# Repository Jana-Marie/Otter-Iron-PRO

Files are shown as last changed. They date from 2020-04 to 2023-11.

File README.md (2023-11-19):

# Otter-Iron-PRO

USB-PD soldering station for JBC C245 handles based on the [Otter-Iron](https://github.com/Jana-Marie/Otter-Iron).

 - v1.0 tested, works but not great
 - v1.1 untested, wont be tested
 - v2.0 tested, kinda works, could be much more stable

## Firmware

 - Requests and configures for USB-PD profile of 30 W or 80 W (allows variable).
 - Current limit automatically set based on PD profile available.
 - Profiles can be changed in firmware and enumerated profile will show at start up.
 - Prevents MOSFET driving if no/incompatiable USB-PD profile is advertised; allows setup/flashing with standard USB port.

## v2.0

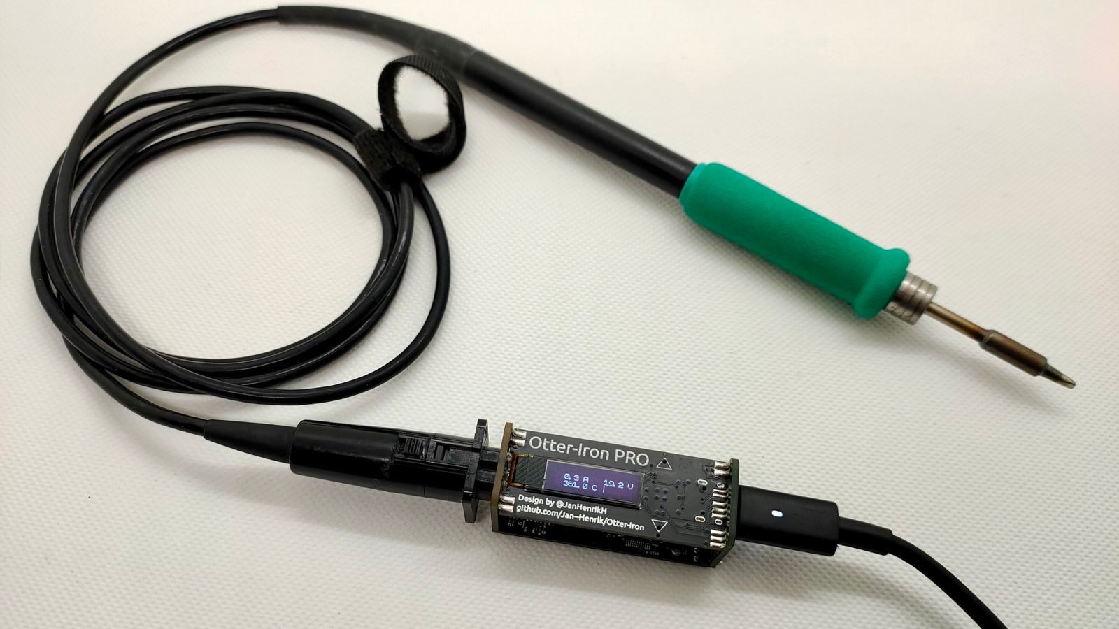
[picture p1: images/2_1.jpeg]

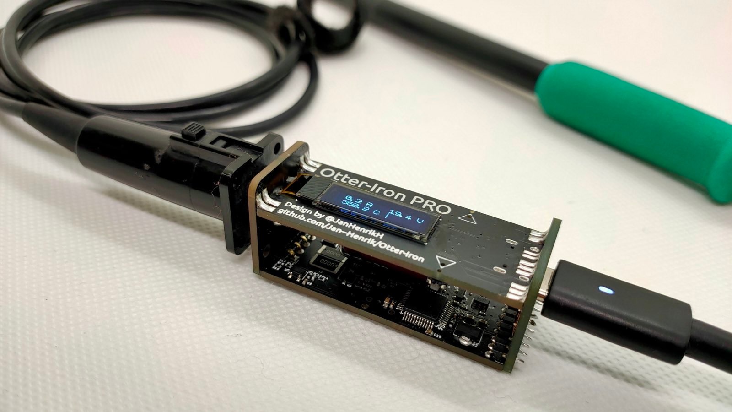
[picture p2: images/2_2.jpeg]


## v1.0

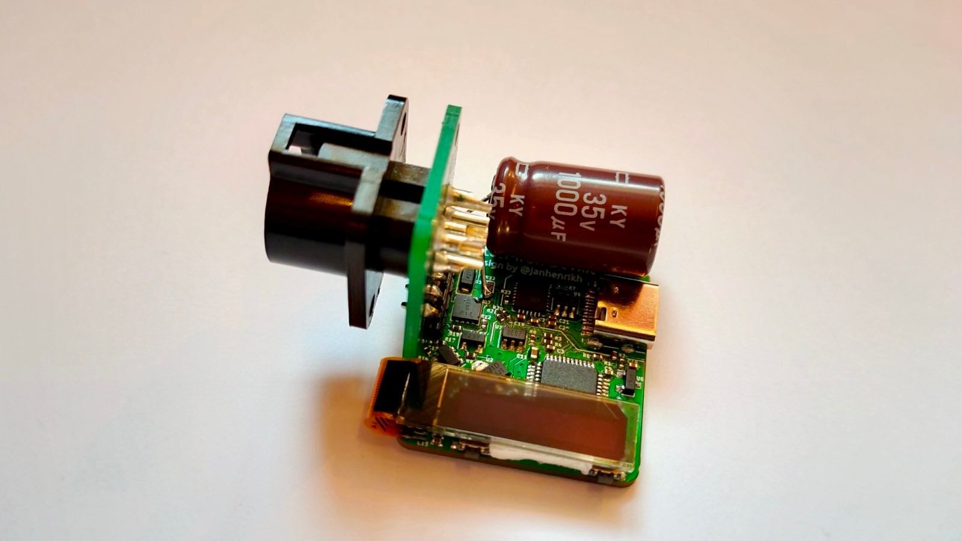
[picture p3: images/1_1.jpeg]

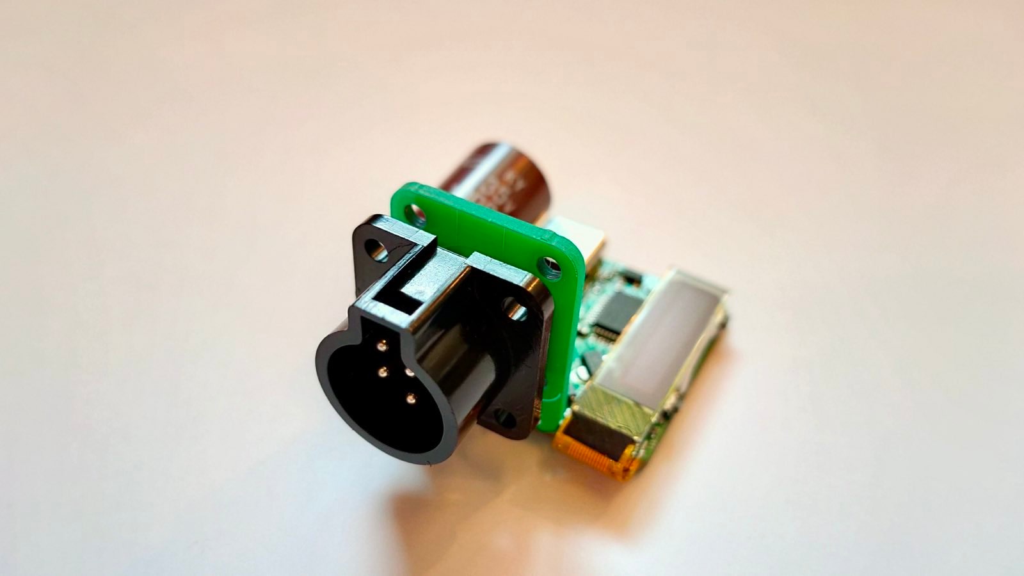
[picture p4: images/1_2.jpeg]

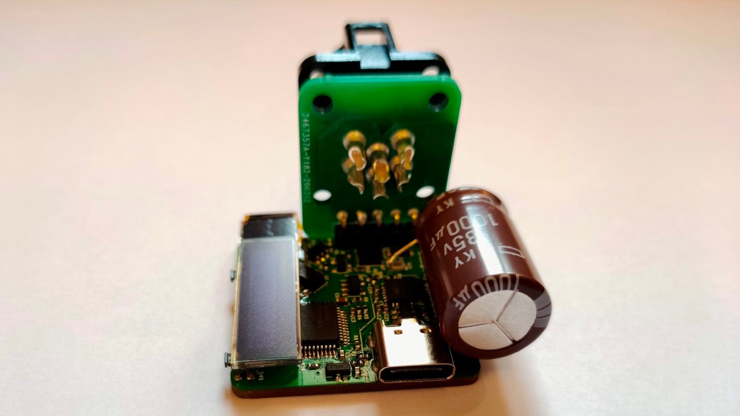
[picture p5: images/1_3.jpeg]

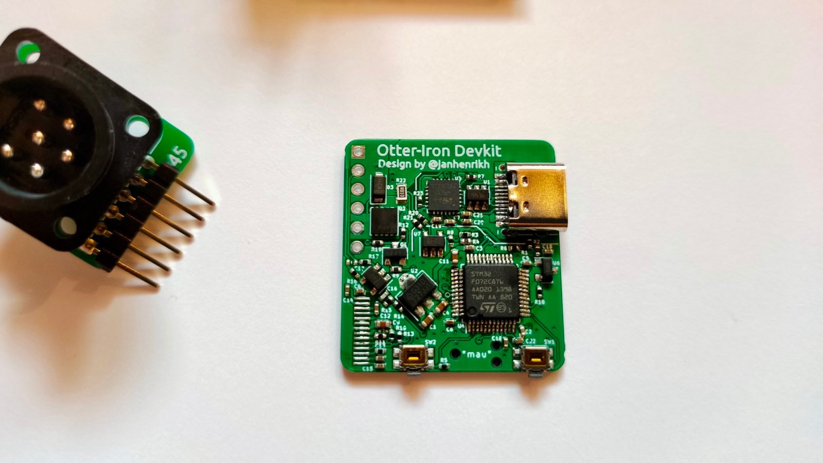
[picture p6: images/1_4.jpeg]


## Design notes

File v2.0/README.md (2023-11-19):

[BOM](https://github.com/jeanthom/Otter-Iron-PRO-BOM)




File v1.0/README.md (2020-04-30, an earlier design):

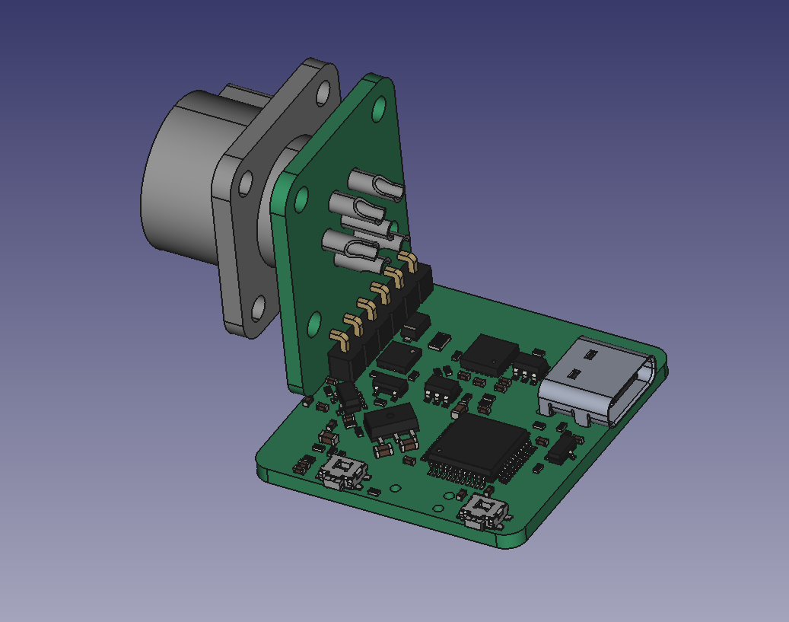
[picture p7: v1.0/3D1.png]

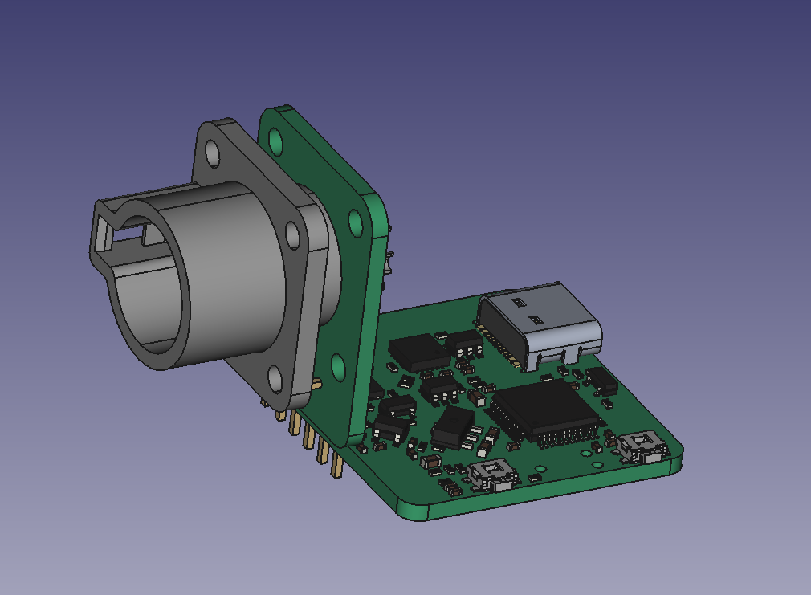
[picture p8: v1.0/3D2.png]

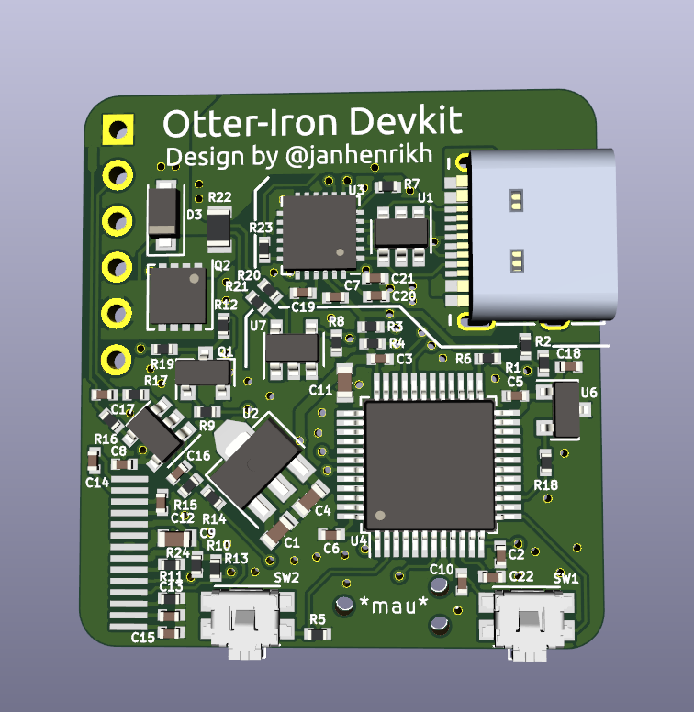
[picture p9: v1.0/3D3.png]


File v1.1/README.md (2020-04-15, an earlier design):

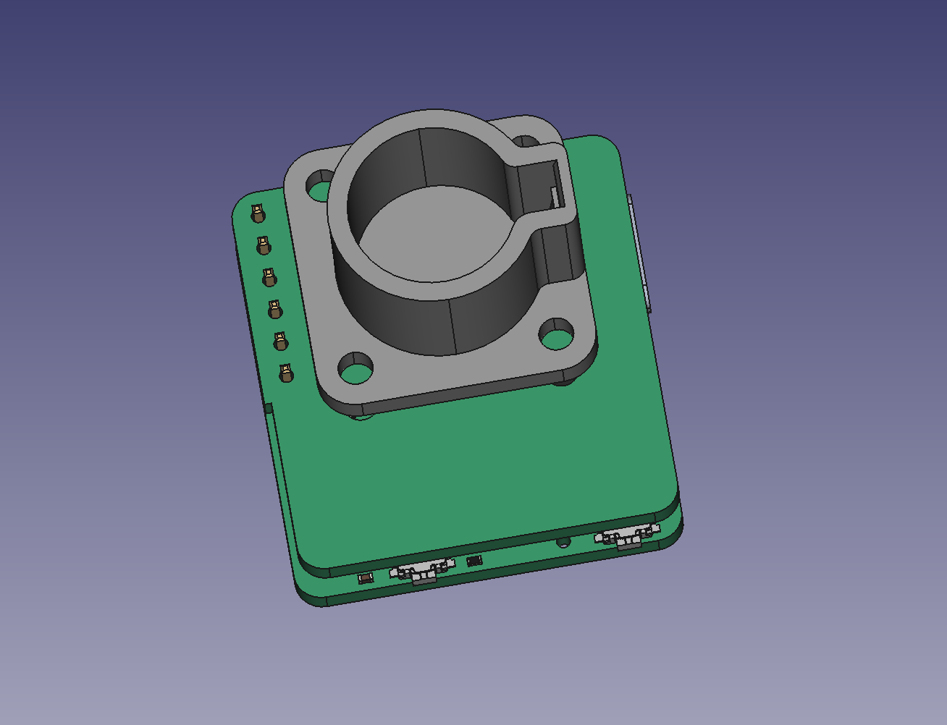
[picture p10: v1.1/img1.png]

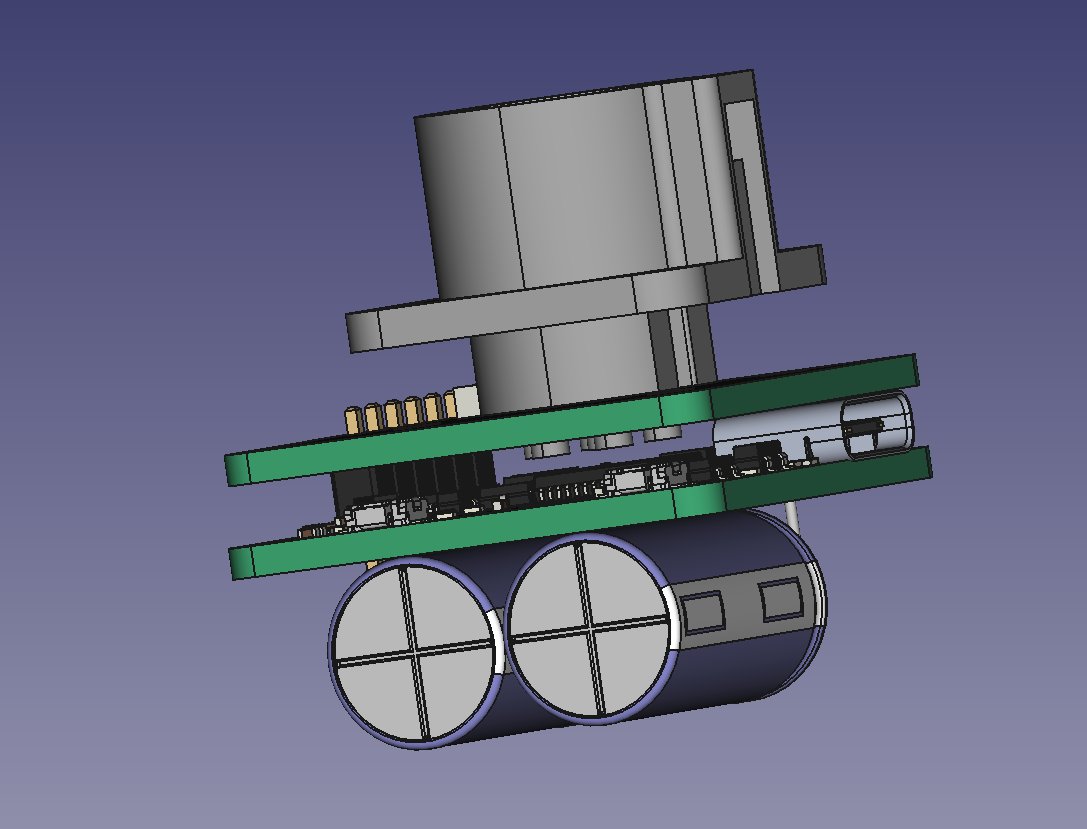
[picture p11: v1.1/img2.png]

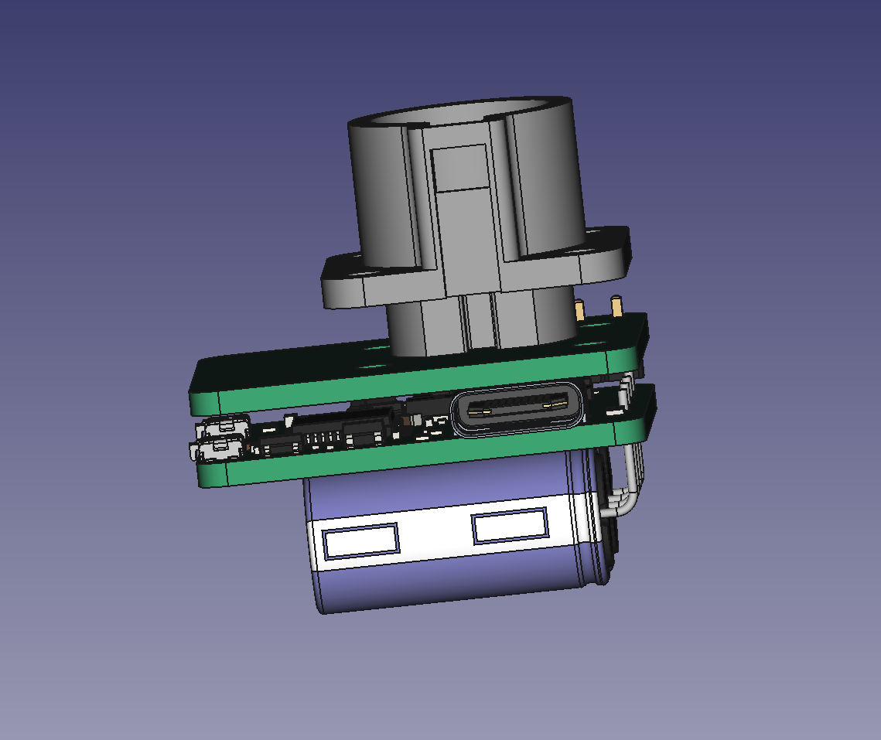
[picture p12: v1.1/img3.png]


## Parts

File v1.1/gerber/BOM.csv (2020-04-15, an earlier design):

Comment | Designator | Footprint | LCSC
1μF 25V | C1,C4,C11,C9 | otter:C_0603 | C15849
1μF 25V | C15,C13,C14,C12,C20,C19 | otter:C_0402 | C52923
18p | C16 | otter:C_0402 | C1549
DNP | C17 | otter:C_0402
0.1μF | C3,C5,C7,C8,C10,C2,C18,C6,C21,C22 | otter:C_0402 | C1525
B140-E3 | D3 | Diode_SMD:D_SOD-123F | C64891
USB_C_Receptacle_USB2.0 | J1 | otter:USB-C 16Pin | C319148
OLED_64x32 | J2 | otter:0.69OLED
C245 | J3 | Connector_PinHeader_2.54mm:PinHeader_1x06_P2.54mm_Vertical
JUNC_N | NT1 | NetTie:NetTie-2_SMD_Pad0.5mm
TC2030-CTX | P1 | otter:TC2030
SS8050 | Q1 | Package_TO_SOT_SMD:SOT-23 | C2150
DMP3017SFG | Q2 | otter:Diodes_PowerDI3333-8 | C461072
560k | R1,R11 | otter:R_0402 | C132339
750k | R15 | otter:R_0402 | C122545
20 | R19 | otter:R_0402 | C25089
100k | R2,R17 | otter:R_0402 | C25741
33 | R20,R21 | otter:R_0402 | C25105
10m | R22 | otter:R_0805 | C50732
2k37 | R5,R3,R4,R6,R12,R9,R10,R13,R16,R14,R18,R7,R8,R23,R24 | otter:R_0402 | C25881
key1 | SW1 | Button_Switch_SMD:SW_SPST_EVQP7C
key2 | SW2 | Button_Switch_SMD:SW_SPST_EVQP7C
USBLC6-4SC6 | U1 | Package_TO_SOT_SMD:SOT-23-6 | C111212
AP2204R-3.3 | U2 | Package_TO_SOT_SMD:SOT-89-3 | C156303
STUSB4500QTR | U3 | otter:QFN-24-1EP_4x4mm_P0.5mm_EP2.7x2.7mm
STM32F072C8Tx | U4 | otter:LQFP-48_7x7mm_P0.5mm | C80488
OPA340NA | U5 | Package_TO_SOT_SMD:SOT-23-5 | C73479
MCP9700AT-ETT | U6 | Package_TO_SOT_SMD:SOT-23 | C127949
SI8540 | U7 | Package_TO_SOT_SMD:SOT-23-5

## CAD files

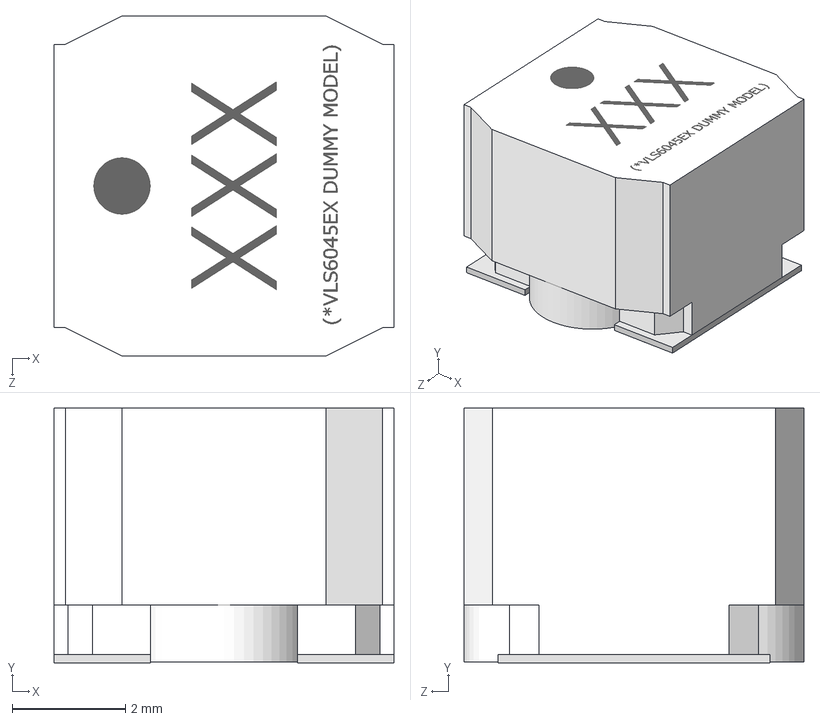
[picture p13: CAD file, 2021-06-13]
v2.0/Bottom/vls6045ex.step
6.00 x 4.50 x 6.00 mm
VLS6045EX_C(3Dmodel)
VLS6045EX_T(3Dmodel)

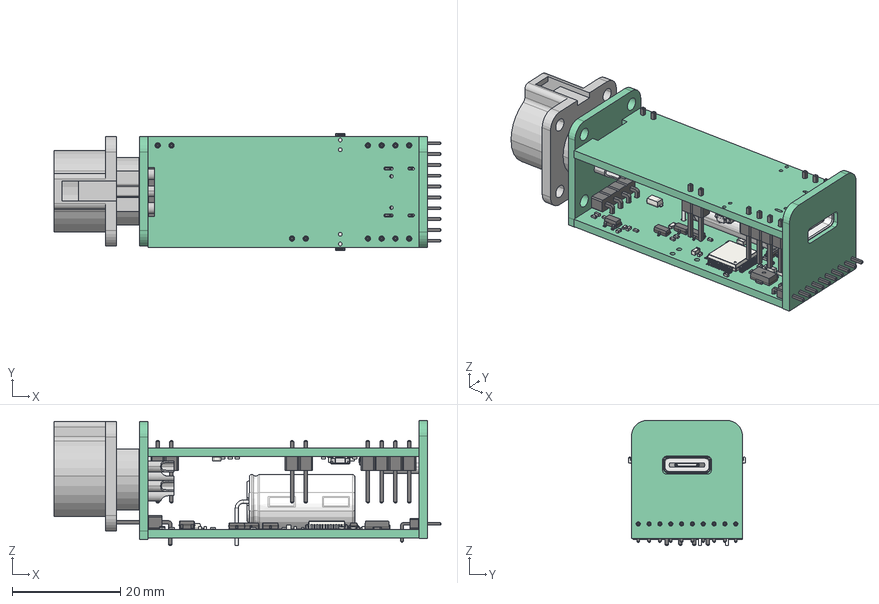
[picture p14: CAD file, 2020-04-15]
v2.0/Stackup.FCStd
71.4 x 21.6 x 23.1 mm
Pcb_2461
J6_PinHeader_1x04_P254mm_Vertical_5E93BB02
J5_PinHeader_1x04_P254mm_Vertical_5E93BAEA
J4_PinHeader_1x02_P254mm_Vertical_5E93BAD2
J3_PinHeader_1x02_P254mm_Vertical_5E93BABC
R10_R_0603_1608Metric_5E93AD9D
R24_R_0603_1608Metric_5E93ADFF
R23_R_0603_1608Metric_5E93ADF8
R13_R_0603_1608Metric_5E93ADB2
R11_R_0603_1608Metric_5E93ADA4
R7_R_0603_1608Metric_5E93AD88
C21_C_0603_1608Metric_5E93BA3C
C20_C_0603_1608Metric_5E93ABF7
C19_C_0603_1608Metric_5E93ABF0
C15_C_0603_1608Metric_5E93ABD4
C14_C_0603_1608Metric_5E93ABCD
C13_C_0603_1608Metric_5E93ABC6
C12_C_0603_1608Metric_5E93ABBF
U3_QFN_24_1EP_4x4mm_P05mm_EP27x27mm_5E93AEA4
U1_SOT_23_6_5E93AE5A
SW2_User Library-EVQP7-JA-01P_5E93AE44
SW1_User Library-EVQP7-JA-01P_5E93AE25
J1_USB Type C Port (SMD Type)_5E93AC6F
Pcb_9526
J1_PinHeader_1x10_P200mm_Horizontal_5E95C6C6
U4_LQFP_48_7x7mm_P05mm_5E93AEFF
J3_PinHeader_1x04_P254mm_Horizontal_5E93ACCE
U7_SOT_23_5_5E93AF3E
U6_SOT_23_5E93AF29
U5_SOT_23_5_5E93AF14
U2_SOT_89_3_5E93AE72
R25_R_0402_1005Metric_5E93AE06
R22_R_0805_2012Metric_5E93ADF1
R21_R_0402_1005Metric_5E93ADEA
R20_R_0402_1005Metric_5E93ADE3
R19_R_0603_1608Metric_5E93ADDC
R18_R_0402_1005Metric_5E93ADD5
R17_R_0402_1005Metric_5E93ADCE
R16_R_0402_1005Metric_5E93ADC7
R15_R_0402_1005Metric_5E93ADC0
R14_R_0402_1005Metric_5E93ADB9
R12_R_0402_1005Metric_5E93ADAB
R9_R_0402_1005Metric_5E93AD96
R8_R_0402_1005Metric_5E93AD8F
R6_R_0402_1005Metric_5E93AD81
R5_R_0402_1005Metric_5E93AD7A
R2_R_0402_1005Metric_5E93AD65
R1_R_0402_1005Metric_5E93AD5E
Q4_SOT_23_5E93AD57
Q3_SOT_23_5E93AD42
Q1_SOT_23_5E93AD14
D3_D_SOD_123F_5E93AC4E
C24_capacitor_bertical_mount_5E93AC35
C22_C_0402_1005Metric_5E93AC05
C18_C_0402_1005Metric_5E93ABE9
C17_C_0402_1005Metric_5E93ABE2
C16_C_0402_1005Metric_5E93ABDB
C11_C_0603_1608Metric_5E93ABB8
C10_C_0402_1005Metric_5E93ABB1
C9_C_0603_1608Metric_5E93ABAA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

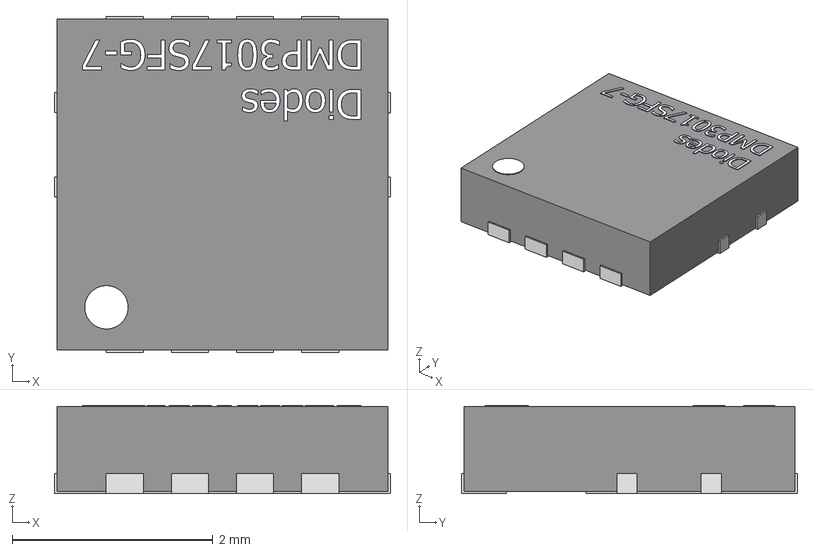
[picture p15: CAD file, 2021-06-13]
v2.0/Bottom/Diodes_-_DMP3017SFG-7.step
3.35 x 3.35 x 0.88 mm

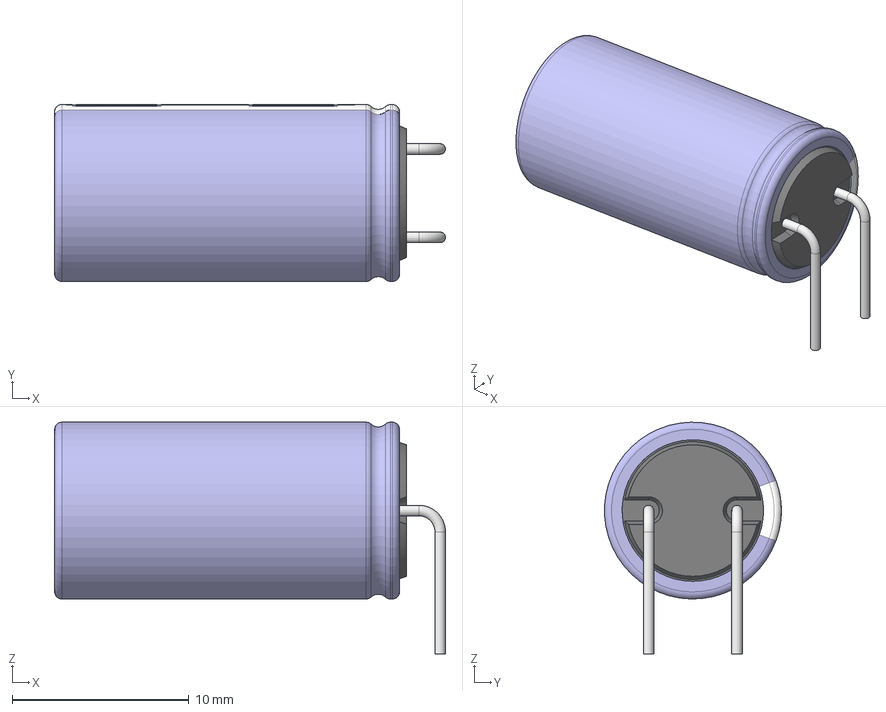
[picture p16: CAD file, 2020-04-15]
v2.0/Bottom/cap_el_horizontal_d10_h20_p5_w0.6.stp
22.1 x 10.0 x 13.1 mm

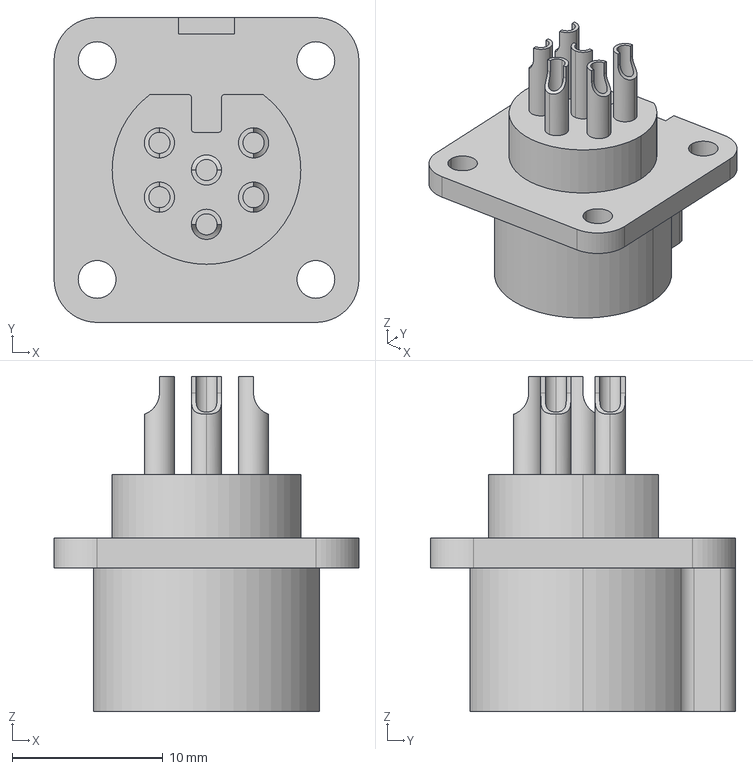
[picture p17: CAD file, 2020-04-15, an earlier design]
v1.0/C245_conn/RPC1-12RB-6P.stp
20.2 x 20.2 x 22.2 mm

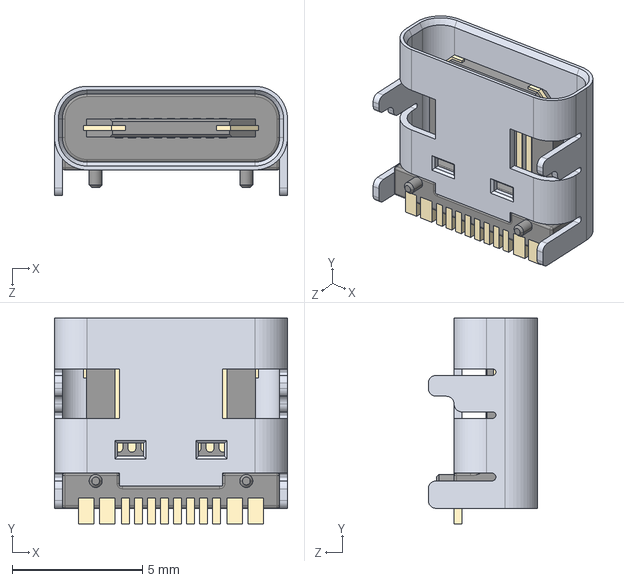
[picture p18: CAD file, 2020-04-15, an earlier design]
v1.0/USB Type C Port (SMD Type).STEP
8.94 x 7.90 x 4.20 mm

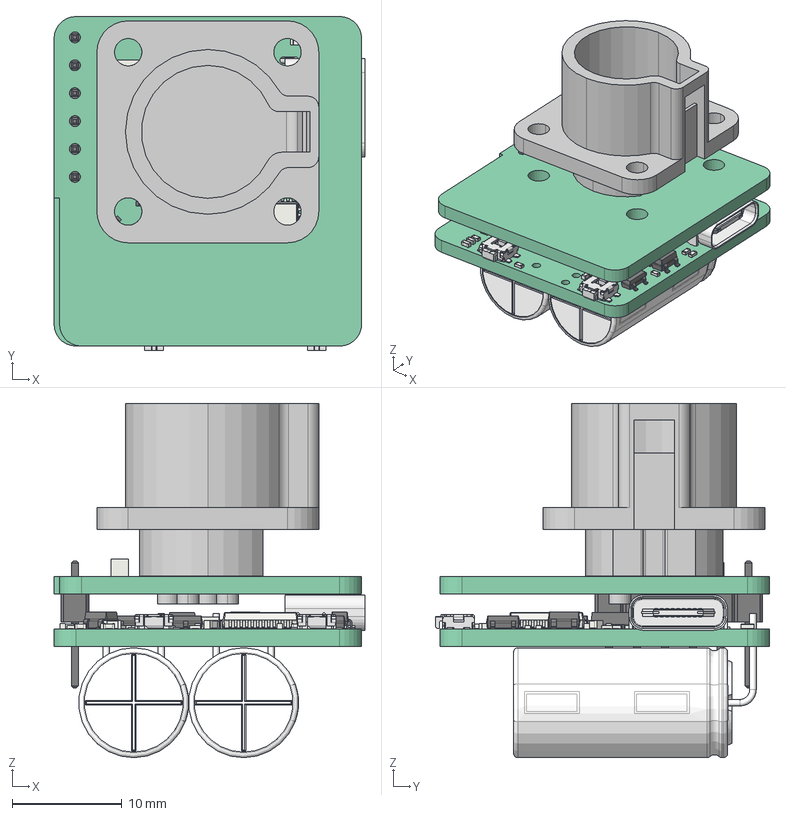
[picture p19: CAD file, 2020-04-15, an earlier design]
v1.1/Stackup.FCStd
28.3 x 30.4 x 32.2 mm
Pcb_544b
R19_R_0603_1608Metric_5E5C1BE8
R25_R_0402_1005Metric_5E938753
Q4_SOT_23_5E93862C
Q3_SOT_23_5E938617
U7_SOT_23_5_5E5C1D64
R20_R_0402_1005Metric_5E5C1BF7
R21_R_0402_1005Metric_5E5C1C06
R8_R_0402_1005Metric_5E5C1B43
U3_QFN_24_1EP_4x4mm_P05mm_EP27x27mm_5E5C1CCF
C9_C_0603_1608Metric_5E5CB203
SW2_User Library-EVQP7-JA-01P_5E5C1C6F
SW1_User Library-EVQP7-JA-01P_5E5C1C52
U4_LQFP_48_7x7mm_P05mm_5E5C2A96
R24_R_0402_1005Metric_5E5CD98E
R23_R_0402_1005Metric_5E5C1C26
R22_R_0805_2012Metric_5E5C3EA5
R18_R_0402_1005Metric_5E5C1BD9
R17_R_0402_1005Metric_5E5C1BCA
R16_R_0402_1005Metric_5E5C1BBB
R15_R_0402_1005Metric_5E5C1BAC
R14_R_0402_1005Metric_5E5C1B9D
R13_R_0402_1005Metric_5E5C1B8E
R12_R_0402_1005Metric_5E5C1B7F
R11_R_0402_1005Metric_5E5C1B70
R10_R_0402_1005Metric_5E5C1B61
R9_R_0402_1005Metric_5E5C1B52
R7_R_0402_1005Metric_5E5C1B34
R6_R_0402_1005Metric_5E5C1B25
R5_R_0402_1005Metric_5E5C1B16
R4_R_0402_1005Metric_5E5C1B07
R3_R_0402_1005Metric_5E5C1AF8
R2_R_0402_1005Metric_5E5C1AE9
R1_R_0402_1005Metric_5E5C1ADA
C22_C_0402_1005Metric_5E5C1A28
C21_C_0402_1005Metric_5E5CA611
C20_C_0402_1005Metric_5E5C1A0A
C19_C_0402_1005Metric_5E5C19FB
C18_C_0402_1005Metric_5E5C19EC
C17_C_0402_1005Metric_5E5C7E34
C16_C_0402_1005Metric_5E5C19CE
C15_C_0402_1005Metric_5E5C19BF
C14_C_0402_1005Metric_5E5C19B0
C13_C_0402_1005Metric_5E5D03B5
C12_C_0402_1005Metric_5E5C8E7E
C11_C_0603_1608Metric_5E93A77E
C10_C_0402_1005Metric_5E5C1972
C8_C_0402_1005Metric_5E5C1952
C7_C_0402_1005Metric_5E5C1943
C6_C_0402_1005Metric_5E5C1934
C5_C_0402_1005Metric_5E5C1925
C4_C_0603_1608Metric_5E5C1916
C3_C_0402_1005Metric_5E5C1905
C2_C_0402_1005Metric_5E5C18F6
C1_C_0603_1608Metric_5E5C18E7
U6_SOT_23_5E5C1D4F
U5_SOT_23_5_5E5C1D3A
U2_SOT_89_3_5E5C1C9D
U1_SOT_23_6_5E5C1C85
Q2_DFN-8-1EP_3x3mm_Pitch0.65mm_5E5C1ACB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

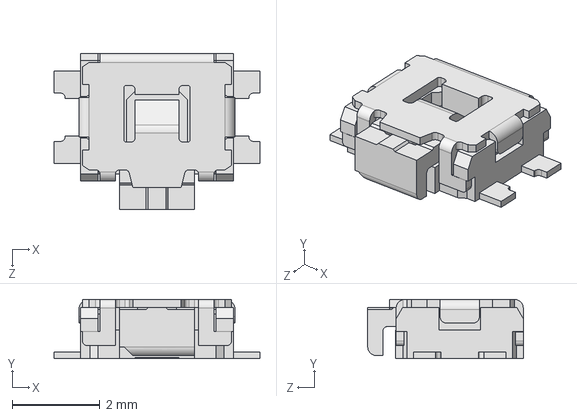
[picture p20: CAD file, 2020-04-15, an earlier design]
v1.0/User Library-EVQP7-JA-01P.step
4.70 x 1.35 x 3.55 mm

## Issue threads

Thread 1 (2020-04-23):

Why using an inductor?

rs-development, 2020-04-23:
Hey,

I am working on a similar project and was wondering why you are using an inductor for powering the iron? My guess, a fast PWM switching alone was not sufficient enough to maintain a decent USB-C Bus voltage? Maybe even triggering the power source?

Or are there some more reasons?

rs-development, 2020-04-23:
But don't get me wrong! Awesome work, ours is far more complex.... you did a good job keeping it simple!

jeanthom, 2020-04-23:
Hi!

I asked Jan Henrik about this:
> L1 is not determined yet, nor is determined if a inductor is needed. The topology with the inductor resembles a Buck-converter, such is may needed due to high pulse currents generated by the tip. However if I can ramp the driver frequency high enough, the inductor is not needed and can be replaced with a 0 Ohm resistor.

rs-development, 2020-04-23:
Ahh good to know, maybe I will try the supply our version with a USB C power supply soon to test this. Fell free to contact me if you would like to work together in some regard.

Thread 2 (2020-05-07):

About L1 on v2.0 bottom PCB...

rsre, 2020-05-07:
Hi Jan,

A few friends and I were having a look at your design and we couldn't understand the purpose of L1 inductor on the Bottom PCB of v2.0.

Then we saw the picture of the assembled prototype and realised you had two 0 ohm resistors soldered there. Are you using them as fuses or for something else? Did you use the inductor symbol because it had the pad already designed?

Nice project over all, what are your thoughts regarding the design _doneness_?

Jan--Henrik, 2020-05-07:
Hey, I added L1 in case, if there is a energy storage needed (to reduce current spikes). However this is not the case and L1 can be bridged with a 0Ohm 2512 resistor.

I had an error on the "USB-PCB", which is now fixed but untested. Beside I think the design is more or less finished.

rsre, 2020-05-07:
Thanks for the quick answer. So, just to check, would it be OK to remove L1 from the design?

Jan--Henrik, 2020-05-07:
It is!

Closed 2020-05-30.

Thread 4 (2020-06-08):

Parts list

designingSparks, 2020-06-08:
Interesting project! Do you have a parts list, in particular for the soldering iron and USB 3 connector?

Jan--Henrik, 2020-06-08:
Hey, you can find the BOM here: https://github.com/jeanthom/Otter-Iron-PRO-BOM
:)

Closed 2020-06-29.

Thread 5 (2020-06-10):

Might be a silly question but...

dreamcat4, 2020-06-10:
Hey I was really thinking about these projects today (not just yours, but also by others out there) and wonder why you choose STM32 platform as the MCU? The reason I ask is because I see that the ESP32 is pretty cheap now less than $3. And it has a high performance and very good timing precision. Plus 2 cores. So could that be a better MCU platform, for driving the JBC tip and updating the display?

Maybe I feel it is somewhat a missed opportunity. That nobody else on the internet has yet made any JBC controller based around the ESP32. After having researched STM32 hardware variants today (a lot - yes the whole day is lost to that!) for a 2 other Open Source Firmware projects. It seems they release many variants in the hardware it can really break things silently when you end up with a chip that 'looks the same'. But is actually NOT behave exactly the same. I think this is currently my main personal hell with STM32. While looking online to source another chip to match / replace. It is indeed a hell...

Yet elsewhere we can easily buy an ESP32. And (for sure) its always the same. For what $1 - $2 USD more to the BOM cost? While also getting a higher performance etc. What am I actually missing here?

Sorry I don't mean to say you should now switch all your MCU platform now for this device. Since its already done! I am instead trying to ask if you can imagine:

If you knew those things today, and had to evaluate which platform to choose for this project.... would you still again choose STM32 (same choice?). Or would you instead maybe want to go with ESP32 instead?

I am asking because we were discussing elsewhere this very matter: What is actually best choice for MCU platform. For other similar projects. And to get the best community involvement. So your comments / insights are so much appreciated. Clearly the otter pro is such a nice project. And a great success of itself. I hope you understand the purpose. Since we all are talking about other similar open source hardware projects. Thank you.

dreamcat4, 2020-06-13:
OK thanks again we seem to have run this discussion out. Grateful of those commentary. Closing but by all means can still add further discussion if you wish. I might come back myself after a long time with findings from other projects.

BTW I also wanted to mention this other project, because it uses an even lower performance MCU than your 072 (it's an arduino). While OTOH with really more powerful mosfets and power circuitry etc. for driving the heater element. Perhaps "somewhat excessive", or over built.

https://github.com/Canonius/JBC_Soldering_Station

The thing is it's heat up time is worse performance compared to an original JBC station. Perhaps the firmware could be improved if it's not being limited by the MCU itself. Just as an example where they went with even slower MCU (than this STM 072 that you choose here).

So I was wondering if MCU choice is really not matter. Such as with above example project. In fact I also wish to be building (yet another) different Ardunio based controller design (by forum user 'xDadu'). Due to it's exceptionally low BOM cost. As I am also curios to see how well the performance can be for such a low materials cost. If anything can be learned from that.

Closed 2020-06-13.

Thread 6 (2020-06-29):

Crashing calculating differential error

tuna-f1sh, 2020-06-29:
Built up this assembly with no problems - great build, thanks!

Had issues bring the firmware up however. The system would crash and reboot just as it entered the deadband and PID control kicked into life. Some brute force debugging commenting out lines, it appears to be at the differential error calculation:

[r.derror = (r.error - r.errorprior)/r.cycletime;](https://github.com/Jan--Henrik/Otter-Iron-PRO/blob/6000d8772d094b828b030de3172646b6571c6a82/firmware/Src/main.c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)

Removing this line it works fine. Can't figure out why? Thought maybe divide by zero but cycletime is constant non-zero. The differential term isn't even used by default so it is not even doing anything of use. It's not due to a brown out as I even tried it without using the calculated duty setting and it still falls over (might be related to crashing without tip installed?).

I guess you've not encountered the same issue? I'm using GCC 10.1.0 so might be due some compiler optimisation?

Jan--Henrik, 2020-06-29:
Hey, nice to hear that you've successfully built an otter-iron pro!

This is strange, such a bug is usually caused by a buggy version of GCC, but version 10.1 is actually quite good and should work! I use gcc v9.2.1 and I have not encountered this issue.

Since the d-term is not used you have the following options:
 - Remove the line and use as is
 - Try gcc v9.2.1
 -  Flash the prebuilt binary contained within the repository

tuna-f1sh, 2020-06-30:
Thanks. Yes I agree very odd, I verified a few times to make sure I wasn't doing something stupid. I'll give it a bit more digging when I've got time. I also plan on implementing some STUSB4500 features such as detection of valid PD profile before attempting to power the iron.

I had the system working by removing the line, as you say but just wondered if anyone else had experience this. I couldn't use the pre-built binary because I needed to limit the current to 3.0 A rather than 4.0 for my 65 W USB-PD upstream device.

I had one unrelated question: How did you select the tip offset and coefficient? Did you use a thermal sensor? Do you think the values are representative for another C245 handle and tip?

tuna-f1sh, 2020-07-01:
Did a bit more testing to see if I could get to the bottom of this, for personal knowledge if anything. The watchdog is biting and resting the system so that line is taking too long for some reason:

* Tried replacing`r.cycletime` with 1.0 - this fixes it.
* Seems like the line with `r.cycletime` of 0.0000725 causes the calculation to take too long and the watchdog to bite.

Since the Cortex-M0 doesn't have an FPU and it's a divide operation, seems plausable. Not sure why it's only happening on my build with GCC 10.1 though. Tried setting optimisations to `O0` but same result. Anyway, not got more time to sink into this since it's not even required with the current build missing the D term but would be nice to know the cause! Feel free to close this.

I have a [fork](https://github.com/tuna-f1sh/Otter-Iron-PRO) with ST4500 setup for PD (allows it to work with kosher PD adaptors like Apple MacBook), better iron detection based on outside dead-zone current and (I think) correct OLED setup (I had problems with screen start-up on some boots with current firmware). Let me know if you want a pull request.

Jan--Henrik, 2020-07-01:
> I couldn't use the pre-built binary because I needed to limit the current to 3.0 A rather than 4.0 for my 65 W USB-PD upstream device.
All power supplies that I use also provide only 65W, I've set the current limit to 4A because it is slightly off. My the f072 does not have enough peripherals/peripheral events to sample the current while it is flowing (Mosfet on) and the temperature, which needs the mosfet to be turned off. I couldn't come up with an elegant solution, thus I implemented the measurement to run in sync with the PWM, right before a new cycle starts. This solution would measure no current, if the frequency would be the same as with my TS100 clone (~10Hz).
To be able to measure and limit the current, the frequency has been increased to 10kHz and a smoothing capacitor was added. This works (for me) with a empirically measured current limit of 4A :D

> I had one unrelated question: How did you select the tip offset and coefficient? Did you use a thermal sensor? Do you think the values are representative for another C245 handle and tip?

Yes and probably! You can set both values to zero, measure the tip temperature at room temperature and use the difference as offset. For the coefficient set the tip temperature to whatever (>100°C) your temperature measuring device can handle and calculate the multiplication factor to match both temperatures. This does not need to be exact since +-5 degrees or more usually won't hurt your board/parts.

Jan--Henrik, 2020-07-01:
> Let me know if you want a pull request.

Yes please! Especially the PD detection has been on my todo for a long time now and I've heard from many people that the display causes problems! Thank you very much for your effort! :)

Jan--Henrik, 2020-07-01:
May I also merge your code into the firmware of the [Otter-Iron](https://github.com/Jan--Henrik/Otter-Iron)? I want to add a "select-the-highest-possible-voltage" function, allowing the use of 9V and 12V power supplies. (schema: Try 20V, if not available try 15V, 12V, 9V)

Jan--Henrik, 2020-07-01:
Also thanks for the info on the D-Term, which is really a strange and interesting bug. I won't pursue this any further and close the issue.

Closed 2020-07-01.

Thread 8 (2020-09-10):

Add overheating protection/temperature amplifier saturation?

jeanthom, 2020-09-10:
Hi everyone,

Yesterday I ran into an issue with my Otter Iron PRO: the tip became glowing red hot! What happened is that I set its temperature to 400°C, and as the temperature readout was saturating at ~390°C the controller sent full power (65W) to the tip. What surprised me the most is that after letting the tip cool off, it still works (if I set the temp to < 390°C).

I'm using Jabe tips, not the JBC ones so that could explain the issue with the temp readout.

Has anyone here tried to run their iron at more than 390°C?

Jan--Henrik, 2020-09-13:
This is... ..new. I hope that it did not ruin your cartridge.
I will try to recreate the situation and find a fix. Is there anything else you noticed?

jeanthom, 2020-09-13:
To my biggest surprise, the tip is still functional! I was able to finish my VQFN bodge job, but I'm going to order a new one anyway just to be sure.

Yesterday I received some other kind of C245 tips. I still have the 390°C saturation issue, plus the temperature is super unstable (like ±20°C). I will try to investigate on my scope what's being sent to the ADC.

Jan--Henrik, 2020-09-13:
Please share the results! However I highly suspect my shitty control loop for being the cause. You might also want to try to tune it for better results

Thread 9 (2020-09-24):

Seem to not find the L1 inductor

ejaboz, 2020-09-24:
Hi, i want to try out on this board but seem to not find the Inductor and on the picture i can see you have 2x1000 metrics. In Schematics it says it is 4.7u "Inductor choke coil reactor magnetic" but i have looked for some hours and seems to find nothing that matches that with both picture and description. Have you changed inductor or is it still the same and 2x1000 metric 4.7u and where can you get them?

Jan--Henrik, 2020-09-25:
Hey, please replace the inductor with a 0 ohm jumper (2512). I need to fix the bom

Closed 2020-09-26.

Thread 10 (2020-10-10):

USB ! USB-PD Error Message

sleepiwill, 2020-10-10:
Hi Jan,

I'm trying to troubleshot the "USB ! USB-PD" message everything I power up my Otter Iron Pro using a Dell 90W USB C Power Adapter.
Before I start pulling my hair out along with the components what do you recommend I check first to get the iron working?

Thanks,
Sleep

Jan--Henrik, 2020-10-24:
Hey,
despite the message, does the power supply put out 20V?

ElRoberto538, 2020-12-11:
I am getting the same issue using an 87w Macbook pro charger, it does support 20v 4.3A PD. Also tested on my work 60w USB-C screen, but I don't know what power profiles it supports. The Otter Iron only outputs 5v with this message showing. I checked all of the stusb connections and it looks good, can't find anything wrong physically. It is happening on both of the Otter Iron pros I've assembled.

@sleepiwill Did you solve this? I am about to update the firmware to display USB PD stats on the screen so I can debug this (I am an STM32 noob so not sure if there's an easier way).

ElRoberto538, 2020-12-13:
Ok, so I think I've solved this issue, [here](https://github.com/jeanthom/Otter-Iron-PRO-BOM/issues/7). I think we are both using the wrong USB interface chip!

swissfreek, 2020-12-19:
Glad I decided to troll the issues pages as I wait for parts for my build. The part number listed for LCSC is the "L" version, and they don't have a non-L version, but DigiKey has them, so I got a couple there.

Closed 2021-04-19.

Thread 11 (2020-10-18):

Issues with Lenovo 4X20M26272 65w USB-C charger

jeanthom, 2020-10-18:
Hi,

I noticed a common issue among USB-C peripherals that are connected to this very specific model of charger: you can hear a faint whine noise, and there is a 1V ripple on VBUS (I'm probing C24 in AC mode in the picture below):

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

This is due to a too big capacitance on VBUS (USB spec specifies max 10µF). I remember fixing an FPGA board with a fat ass inductor but I'm not sure that this is a good solution.

This might explain the issues I'm facing in #8

Jan--Henrik, 2020-10-18:
Hey, I tried to replicate that and indeed it seems to be the same with my Lenovo 65W PD supply, but also my other supplies. This is a problem that needs to be fixed. Thank you for bringing this to my attention :)

hannesweisbach, 2020-10-20:
Did you capture that trace with or without the tip connected/on?

jeanthom, 2020-10-20:
With the tip on. When I disconnect the handle I don't have such oscillations.

hannesweisbach, 2020-10-20:
Ok.

If I see that right, the oszillations have a frequency of rougly 3 kHz. Does that track with the PWM frequency of the otter iron?

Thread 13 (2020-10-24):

LCD Reset -> v2.1?

martin2250, 2020-10-24:
Hi Jan,

as we've talked about, I had issues with the LCD not being reset properly (PCB v2.0) and having the LCD show only random pixels. I tried to solve this by soldering a capacitor (100nF) between LCD reset and GND. For fast-rising power supplies, this keeps the reset line low for long enough to properly reset the LCD.
My power bank, however, has a slightly higher rise time for the output voltage, so this didn't work and I had to resort to soldering a bodge wire from one of the GPIO pins (A10) to the LCD reset line (not very fun when the PCBs are already soldered together :wink: ).

Since all pins of the 10 pin header are already used, I suggest we connect the GPIO pin of the STUSB chip to the LCD reset. That way, we can reset the LCD via I²C and not use any additional connections between the PCBs.

Also I'd change all passives on the top PCB to 0402, since it uses the same values as the bottom PCB anyways.

Cheers!

Jan--Henrik, 2020-10-24:
Hey!

I do like both ideas and will implement them with v2.1! :)
Thank you for your input!

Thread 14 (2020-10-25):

possibly killed by QC power supply?

martin2250, 2020-10-25:
So I was  experimenting with a power bank, which takes a long time to recognize the device and deliver power to the USB port. To test if the LCD powers on immediately when power is applied, I connected the Otter Iron to a "dumb" QC wall wart (12V max, USB-A to C cable), which should supply 5V regardless of whether or not a sink is attached. After a while, the board got hot around the STM/voltage regulator area. Now it doesn't power up anymore and always gets hot, even when connected to a PC. I can feel the STM32 itself warming up, which isn't a good sign.

Do you have any clue on what could have destroyed the STM32?

Jan--Henrik, 2021-06-13:
Hey, sorry for the late answer. Is this issue still active? It might be a defective LDO or cap

martin2250, 2021-06-13:
Hi, you did fix the board for me (thanks again!), but I don't think this issue was investigated further (I certainly won't test it again :D). From my end you can close this issue, but it might appear again...

Closed 2021-06-14.

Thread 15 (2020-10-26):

简·亨里克 / 水獭铁PRO

JHS1211, 2020-10-26:
Your soldering station really looking at very good, I'm not very understand for programming, you can put the firmware generated HEX file? So it is convenient, thank you very much.

Jan--Henrik, 2020-10-26:
Hey, thanks you!
You can find the current release here: https://github.com/Jan--Henrik/Otter-Iron-PRO/releases/tag/v0.2

JHS1211, 2020-10-26:
PCB, thank you very much, I'm ready to play.

Closed 2020-10-26.

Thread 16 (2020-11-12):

Incorrect connection of the TC and heater

richard-sim, 2020-11-12:
Hey, I was looking over your schematic and it looks like you're powering the heater through the TC as they're connected in series in the cartridge with the 3 wires being either end and the common point between them. Going by the Bottom schematic, C245_JUNC is the common connection between the heater and the TC, so the heater should be powered by J3.1 (V+/heater) and J3.3 (C245_JUNC/common), and the TC sensed between J3.4 (TC) and J3.3 (C245_JUNC/common).

dreamcat4, 2020-11-12:
This **[eevBlog Forium thread](https://www.eevblog.com/forum/projects/yet-another-controller-for-jbc-t210t245/)** discussion goes into a lot of details about the C245 Tip. And is the best source of information I have found on the subject. It's probably worth the time to read the comments over there.

richard-sim, 2020-11-14:
There's an even better EEVblog forum post where someone has reverse engineered the entire circuit of a JBC CD-2BC: https://www.eevblog.com/forum/testgear/jbc-soldering-station-cd-2bc-complete-schematic-analysis/

If you look at that schematic, in the middle of sheet 2 is the TC. First thing it goes through is an analog switch that selects between various combinations of the 3 pins on the cartridge. Apparently for the T245 handle it selects TC+COM, and at startup and when a handle is plugged in it selects TC+TC (for zeroing?). I'm pretty certain that if they'd tried with a T210 handle they'd have found it selects LOAD+TC due to the different wiring of the cartridges.

Following that, the schematic also makes it clear that both C245 and C210 cartridges will have their heaters powered through the COM and LOAD pins only - never the TC/earth.

Here's a diagram I found in the Unisolder thread over at the Dangerous Prototypes forum. The T210/C210 connections do not match anything else that I've found online, however they fit the circuit above, and more importantly all my C210 cartridges corroberate it. As far as I can tell, all the "TC+heater are series only for C210" claims are wrong.

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

Closed 2021-06-13.

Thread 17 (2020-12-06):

Debugging tips

ElRoberto538, 2020-12-06:
Hi, this is an awesome project (thanks!). I've managed to assemble mine after finally getting all of my parts, however I can't get it to boot into USB DFU mode, looking at the schematic it seems holding down SW2 while plugging it in should work, but I'm not seeing it listed using lsusb. I've checked a few pins and I can see that the STM32 is receiving 3.2v, and when holding down SW2 the boot pin also gets 3.2v.  One thing I noticed is that the current sense IC (U7) seems to be getting hot, I've checked most of the connections in that part of the circuit and nothing seems to be shorted. Any tips/recommended tutorials to debug this? I have some more parts so I can give it another go, but the soldering on the one I assembled looks good so I'd like to try and fix it.

ElRoberto538, 2020-12-06:
Well, I think I found the reason for the hot current sense IC, I accidentally used a 10M ohm not 10m ohm resistor... I don't think that would stop the STM32 booting though?

jeanthom, 2020-12-07:
I think your STM32 is toasted :confused: With R22 = 1Meg, you'll probably have the IN net at 24V-ish, which is directly fed into the STM32 ADC.

jeanthom, 2020-12-07:
Do you have an ST-Link debug adapter, like the ones you can find for dirt cheap on AliExpress?

ElRoberto538, 2020-12-07:
Ah yes, I didn't consider that... no I don't have one, I'll order one to try and flash it that way to confirm. Unfortunately shipping from china is fairly slow so I've started assembling a second one. I'll leave the sections separate (connect with wires first) this time so it's easier to debug! Do you see an issue with shorting R22 just to get it to boot and flash the firmware while I wait for new 10m resistors to arrive?

Thanks for your help!

jeanthom, 2020-12-07:
Where are you located? If you are in Europe, you should be able to order both the resistor and the STM32 chip from Arrow with free delivery.

Shorting R22 should be okay as long as you don't plug the tip in.

ElRoberto538, 2020-12-07:
I'm in New Zealand unfortunately, I can get free shipping but need to spend $65 minimum! I have enough parts left to complete a new one, so I'll see if I can flash a new one over USB by shorting R22 - thanks again for the help.

dreamcat4, 2020-12-07:
I looked on the arrow website today. However they do not seem to have such a good part availability as other suppliers? For example: which compatible STM32F072 they have? I do not see:

https://www.arrow.com/en/products/search?cat=&q=stm32f072&r=true

jeanthom, 2020-12-07:
It depends on the kind of part you're looking for. Sometimes they have huge stocks for an obscure part, no stock at all for a jellybean part, and the next day it's the opposite. They're on the expensive side, but with free shipping to EU and USA it remains a good deal.

@ElRoberto538 keep us in touch! :)

ElRoberto538, 2020-12-10:
Success! Kind-of, I made a second Otter Iron Pro, seems I'm getting the LCD reset bug though, 4 out of 5 times I plug it in it displays gibberish. Looks cool when it works though, just need to source a 10m Ohm resistor to test with an actual tip now.

How important is using a grounded USB-C power supply? Will I risk destroying sensitive components by soldering them with the iron tip un-grounded or is it a non-issue?

Thanks, @jeanthom, @Jan--Henrik!

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

jeanthom, 2020-12-10:
Congrats! I have the same OLED reset issue as you, but it's less frequent (I'd say 1 out of 5 times). #13 might have a fix.

My previous soldering iron was a DIY T12 kit from http://smdprutser.nl, which I used to solder my Otter Iron PRO. Most of the time it was not connected to ground, and so far it seems like I haven't destroyed things due to ESD. I'd say it's nice to have, especially if you're working with ESD sensitive devices, but not something critically important.

ElRoberto538, 2020-12-10:
Awesome, that's good to know, thanks for all your help.

Closed 2020-12-10.

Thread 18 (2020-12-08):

Free PCBs/Parts $2.50 shipping

ElRoberto538, 2020-12-08:
I ordered way too many PCBs (they only cost a few cents each!), so I can ship them to people for the cost of shipping (USD $2.50), which for some people will be a lot cheaper than shipping from JLCPCB or similar. I have 20 and should be able to fit multiple in a single envelope if anyone wants. They have black solder mask and lead free HASL. I can also chuck in some of the cheaper parts like transistors, resistors, capacitors etc.

If anyone is interested let me know and I'll put them up on Tindie or provide my email for details or something.

dreamcat4, 2020-12-08:
Hey @ElRoberto538, do you think you could ship to the UK? I could send you the shipping over PayPal. I would like to ask for 2 sets of PCB. If not, then no worries.

quentinmit, 2020-12-08:
I'd definitely be interested. My e-mail address is in my GitHub profile.

I suspect you'll have a lot of interest; you should probably do something like Tindie if it's easy.

dreamcat4, 2020-12-08:
Same here - my email address is in my GitHub profile.

ElRoberto538, 2020-12-08:
Great, I'll contact you both in the morning, it's getting late now. I can send globally via post (in paper envelope, will wrap in extra paper for durability) for NZD $3.50, OR roughly USD $2.50. Given the shipping method I can't make any promises on how well it will handle the trip, however as they're only PCBs I would be surprised if they didn't make it in one peice!

I don't have a PayPal account, but I have accounts in almost every country, or can set it up on Tindie as mentioned.

ElRoberto538, 2020-12-08:
Tindie listing is created - awaiting approval. https://www.tindie.com/products/22106/ @dreamcat4, @quentinmit please try to order via the listing - if it somehow sells out before you can order them I have reserved some for you.

dreamcat4, 2020-12-08:
Thanks! Please let us know once it goes live, by posting another comment here. Really appreciate it.

ElRoberto538, 2020-12-09:
Tindie listing is live; https://www.tindie.com/products/22106/

anuejn, 2020-12-09:
I also have some spare boards (in germany).
If you are interested I can ship them to you.

swissfreek, 2020-12-13:
> Tindie listing is live; https://www.tindie.com/products/22106/

Listing says out of stock. Are they already all spoken for?

I’m in the US, if anyone has extra boards/components, I’m interested in paying to take them off your hands.

ElRoberto538, 2020-12-13:
Hi @swissfreek, yes sorry they all sold out in about 12h. Maybe try contacting @anuejn?

swissfreek, 2020-12-13:
> Hi @swissfreek, yes sorry they all sold out in about 12h. Maybe try contacting @anuejn?

Not surprising, thanks anyway!

@anuejn anything left over? If not I guess I'll be the next person with extra boards to share ;)

swissfreek, 2020-12-15:
> yup I have some spare ones.
> any way to contact you?

Sweet!

swissfreek at gmail

TomHodson, 2021-03-03:
@anuejn Do you still have any left? I'm in Munich and would love to get some! My email is thomas c hodson at gmail and it's also on my github.

danikdd, 2022-02-09:
> yup I have some spare ones. any way to contact you?

Hi there, any spare pls? I have adress in Germany or Czech Republic. many thx for info. Nice day. Daniel

m-kozlowski, 2022-02-09:
PCBs? no problem. but might have trouble getting all the other stuff - my orders for USB-PD controller at tme and farnell are being rescheduled every few weeks for over a year(!)

ElRoberto538, 2022-02-09:
I have 4 STUSB4500QTR USB-PD left over, and I think 6 STM32's. I could send them in an envelope (about ~$1) if someone wants, no guarantees they'll arrive though as I got told off last time by the post service as apparently envelopes are for letters only...

sorki, 2022-07-19:
> I have 4 STUSB4500QTR USB-PD left over, and I think 6 STM32's. I could send them in an envelope (about ~$2) if someone wants, no guarantees they'll arrive though as I got told off last time by the post service as apparently envelopes are for letters only...
>
> Edit: Also looks like I still have some of the other parts like op-amps, mosfets, esd suppression diodes etc

Hi, are these still available? I'm considering a small run of 5 boards but STUSB and STM32F1s are out of stock (available next year..).

ElRoberto538, 2022-07-21:
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

Yes I still have them, just checked and I also have 4x sets of PCBs here too. I have Covid at the moment so am in quarantine, but I could post them in a week or so if you send me a way to contact you for address details.

Closed 2022-07-28.

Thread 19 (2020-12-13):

A question about OLED display

snowman-andy-y, 2020-12-13:
Otter iron Pro is a great idea! I tried to make the PCB and verify it. At present, I only used Huawei mobile phone charger for testing. Unfortunately, it can't display normally: only random points are displayed on the display. I don't know my OLED monitor is compatible or not, I am asking the supplier to provide the manual. I noticed that Martin mentioned this situation in his question. But, I can't display it normally so far.

I also have a question about firmware. If I want to modify firmware, what kind of programming environment do I need? Maybe I have to modify the firmware code to display properly.
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

ElRoberto538, 2020-12-13:
Hi @snowman-andy-y, I have the same issue, try turning it on and off multiple times - mine only works about every 1 in 5-10 times I turn it on. It is a known issue - check [here](https://github.com/Jan--Henrik/Otter-Iron) and scroll to known issues which shows soldering a 100nf capacitor from the LCD reset to ground helps. I haven't done this myself yet, so if you do, please let me know how it goes.

snowman-andy-y, 2020-12-14:
> Hi @snowman-andy-y, I have the same issue, try turning it on and off multiple times - mine only works about every 1 in 5-10 times I turn it on. It is a known issue - check [here](https://github.com/Jan--Henrik/Otter-Iron) and scroll to known issues which shows soldering a 100nf capacitor from the LCD reset to ground helps. I haven't done this myself yet, so if you do, please let me know how it goes.

Thank you very much for your advice! It works! I added 100nF between OLED reset and GND, and the display works normally!

Closed 2020-12-24.

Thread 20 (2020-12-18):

Firmware difference to Otter-Iron (non-pro)

NeoFromMatrix, 2020-12-18:
I wanted to ask if the Otter-Iron-PRO hardware is compatible with the Otter-Iron non-PRO firmware (https://github.com/Jan--Henrik/Otter-Iron).
It seems that the non-PRO has developed a bit further while this repo stalled.

If it is compatible, or one firmware for both hardware versions is desired, do you want to add a note in this repo pointing to the other repo?

Also, thanks a lot for your work, I highly appreciate it! :)

ElRoberto538, 2021-01-17:
From looking at the code, the firmware seems compatible, however it runs at lower power... the updates are to support lower power profiles. I copied them into the pro firmware for testing as I only had a 28w adapter. With the lower power it works fine but takes a long time (30+ seconds) to heat up. Having said that I did borrow a 100w apple adapter and changed the firmware to use the full 100w - it works great!

Unless you need lower power I'd stick with the pro firmware.

Jan--Henrik, 2021-04-19:
Hey! No they are NOT compatible, the PROs PWM and PID loop run at a much higher frequency! Please use the PRO firmware for the PRO.

Both firmwares need bugfixes and the PRO firmware needs to be updated to the non-pro firmware version. I will add that to my todo list :)

Closed 2021-06-13.

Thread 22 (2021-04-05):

Firmware programming?

bb-centrum, 2021-04-05:
Hi, I'm new to programming STM32 micro's and could do with some help. Do you have any instructions to follow now my device is all built?

Thanks

Jan--Henrik, 2021-04-05:
Hey!
Please follow the programming instructions for the Otter-Iron, they are the same.
https://github.com/Jan--Henrik/Otter-Iron#flashing

bb-centrum, 2021-04-05:
Perfect, thank you! All finished and working. Now just to buy the handle!

swissfreek, 2021-04-19:
Sorry, maybe I'm being dense. I saw the instructions on the Otter Iron page, but I don't see where the DFU pins are on the Otter Iron Pro. I can't hold the buttons because it hasn't been flashed yet, right? Thoughts?

jeanthom, 2021-04-19:
Hi, there is no pin to short. You just have to press one of the buttons (don't remember which one) while plugging the Otter-Iron to your computer.

swissfreek, 2021-04-19:
> Hi, there is no pin to short. You just have to press one of the buttons (don't remember which one) while plugging the Otter-Iron to your computer.

Ah yes, of course, the schematic shows SW2 is connected to the boot pin. Thanks! Found out my issue wasn't the board, but the fact that the Mac's USB-C ports are super finicky about only having "real" USB-C devices connected to them. When I plugged the iron in through a USB-A adapter (so, C->A->C...) it worked and I was able to flash.

Closed 2021-04-05.

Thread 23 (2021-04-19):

Some questions

Hysen-ZHANG, 2021-04-19:
Hi Jan, I have some questions:
1. Why is there a large capacitor(1000uF) on the control board ?
2. I know the resistance of the soldering iron tip is 3 ohms, the current of soldering iron is 20V/3Ω=6.67A,
Will it cause the PD power supply to enter the OVP state ？
Thanks.😀

Jan--Henrik, 2021-04-19:
Hey! The caps purpose is to smooth out the current spikes to prevent an OVP state. This isn't an elegant solution nor does it work well. A buck topology can be implemented by assembling L1, however I never did that. :D

Hysen-ZHANG, 2021-04-19:
OK and thanks for your answer.

Closed 2021-04-19.

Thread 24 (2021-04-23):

Troubleshooting Help?

swissfreek, 2021-04-23:
I built my Otter Iron Pro. It seems that everything is in order. It accepted the firmware when I flashed it, so the processor seems to be OK and wired correctly. When I plug it into a PD power supply, I can probe the pins of the capacitor and I get 20.0V, so it seems the PD circuitry seems to be working. But I get nothing on the OLED. Not gibberish, it just doesn't power up. I initially bought the OLEDs from LCSC because why not, they're so cheap. So then I assumed that I got the bogus ones as noted on the Otter Iron page, and bought another pair of Amazon. I swapped them out but get the same result. I assume that they are the same crap components as from LCSC. Not sure where else to get these OLEDs. Curious if anyone has any thoughts. I have a JBC handle, but still waiting on the tips, so I'm not sure if pushing buttons will make the iron heat up. I welcome any thoughts on what I could try to troubleshoot the iron. Thanks!

swissfreek, 2021-04-23:
Found one at DigiKey, so hopefully a reputable component (and definitely not cheap, relatively speaking). https://www.digikey.com/en/products/detail/display-visions/EA-W096016-XALW/8021564

Will try this as well when it arrives... 🤷🏼‍♂️

jeanthom, 2021-04-23:
Out of the two OLED displays I bought at LCSC, one of them was defective...

swissfreek, 2021-04-25:
OK, I guess I will see if I have better luck with the ones I got from DigiKey. This would be 0 out of 4 for me...

Jan--Henrik, 2021-06-13:
@swissfreek any news? :)

swissfreek, 2021-06-13:
No news. Neither iron works properly. I was able to flash one. The other I’m pretty sure I had a bad solder joint in the USB-C connector that was causing a short and now it won’t respond, so I assume I fried the processor. Who knows when I’ll be able to get a new one.

the one I can flash appears to take firmware successfully, but I get nothing on the display when I power it up. Honestly just haven’t had the motivation to dig into it more after all the time I spent building both of them and having them both not work.

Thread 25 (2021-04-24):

Iron heater never powers on.

bb-centrum, 2021-04-24:
Hi!

I have the iron working in the sense it powers on, displays the PD profile info, and then says that it is Active but the heater never comes on. The current temp seems to be working fine. I probed pins 4 and 1 on the connector between the bottom board and the C245 connector board and there was no voltage. Probing between GND and pin 5 on the DMP3017SFG gave zero volts, pin 4 = 0.3v and pin 1 = 0.3v

So something is off somewhere, I'm just not sure where to look next. Any ideas?

m-kozlowski, 2021-04-24:
Sure it says it's active, or "!Active"?
When iron is really active (or at least it thinks it is) there is a graphic Bar, not a text.

Which PD profile is negotiated at boot?

bb-centrum, 2021-04-24:
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

I have two USB C power supplies.

An Anker PowerCore. This negotiates PD1. No graphic bar, it just says !Active (not active)?

I also have a 30W Macbook PSU. This says PD Adjust 4 pm boot. If the iron is not connected then I get a loading bar. Connect the iron and I get !Active again. So I think the Anker one is just not powerful enough, but there looks like there is another issue with still!?

m-kozlowski, 2021-04-24:
Is there any chance that you used 10Mohm as R22 instead of 10mOhm?

bb-centrum, 2021-04-24:
Ooh good shout. I'll check that tomorrow morning

bb-centrum, 2021-04-25:
Yup 10M ohm! I'll get that replaced and then hopefully I'll have a working iron!

jeanthom, 2021-04-25:
Some else had the same issue as you (10Mohms instead of 10mOhms), and they had to change the micro-controller: https://github.com/Jan--Henrik/Otter-Iron-PRO/issues/17

m-kozlowski, 2021-04-25:
Yeah, si8540 output is capped at 8V, but it's still enough to fry stm32

bb-centrum, 2021-04-25:
Well I managed to program the stm32 and it boots all ok, so hopefully mine is fine somehow. I’ll let you know when I get the replacement resistor tomorrow

Closed 2021-06-13.

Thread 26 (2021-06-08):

Incorrect current profiles set for STUSB4500 chip

ElRoberto538, 2021-06-08:
I just got a new 100w USB adapter and had trouble getting more than 15v 3A out of it. I read the datasheet for the STUSB4500 and found that the current setting is based on a lookup table, whereas the code is setting it to an absolute value. To get a working 100w profile I set the profile to 20000mv and 150ma in the main.c file (150 will be divided by 10 in the STUSB4500.c file which gives the 5Amp profile from the lookup table in the datasheet).

This doesn't seem to matter for some chargers, but apparently my new one more closely checks the profile limits. Might be helpful for anyone else with the same issue.

Closed 2021-06-13.

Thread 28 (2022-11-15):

Question: STUSB4500 out of stock - replace with a STUSB4761?

Knarf2807, 2022-11-15:
The STUSB4500 is in all shops I looked for out of stock. I wonder, if I replace ist with a STUSB4761? Another Footprint and another Pinout so I have to change the schematic and the PCB.

I think it will work. What do you think? And why do you connect the VSYS to +3V3? Is it necessery for the OtterIron Pro, because the STUSB4761 has no VSYS like the STUSB4500? I found no reason why it is necessery.

Thanks a lot for your help.

Frank

Jana-Marie, 2022-11-15:
Hey, no the STUSB4500 cant be replaced with STUSB4761. The latter is a source controller, not a sink controller.

Knarf2807, 2022-11-18:
I will try a STUSB4500BJRCT (BGA). Because it's my first time "soldering" BGA, I'm not shure, that it works after my soldering. That's why I will build in a "bypass" and a normal round DC-Plug. I have to think over my idea, but at the moment it's the best I have (can't wait o.O )

Closed 2022-11-15.

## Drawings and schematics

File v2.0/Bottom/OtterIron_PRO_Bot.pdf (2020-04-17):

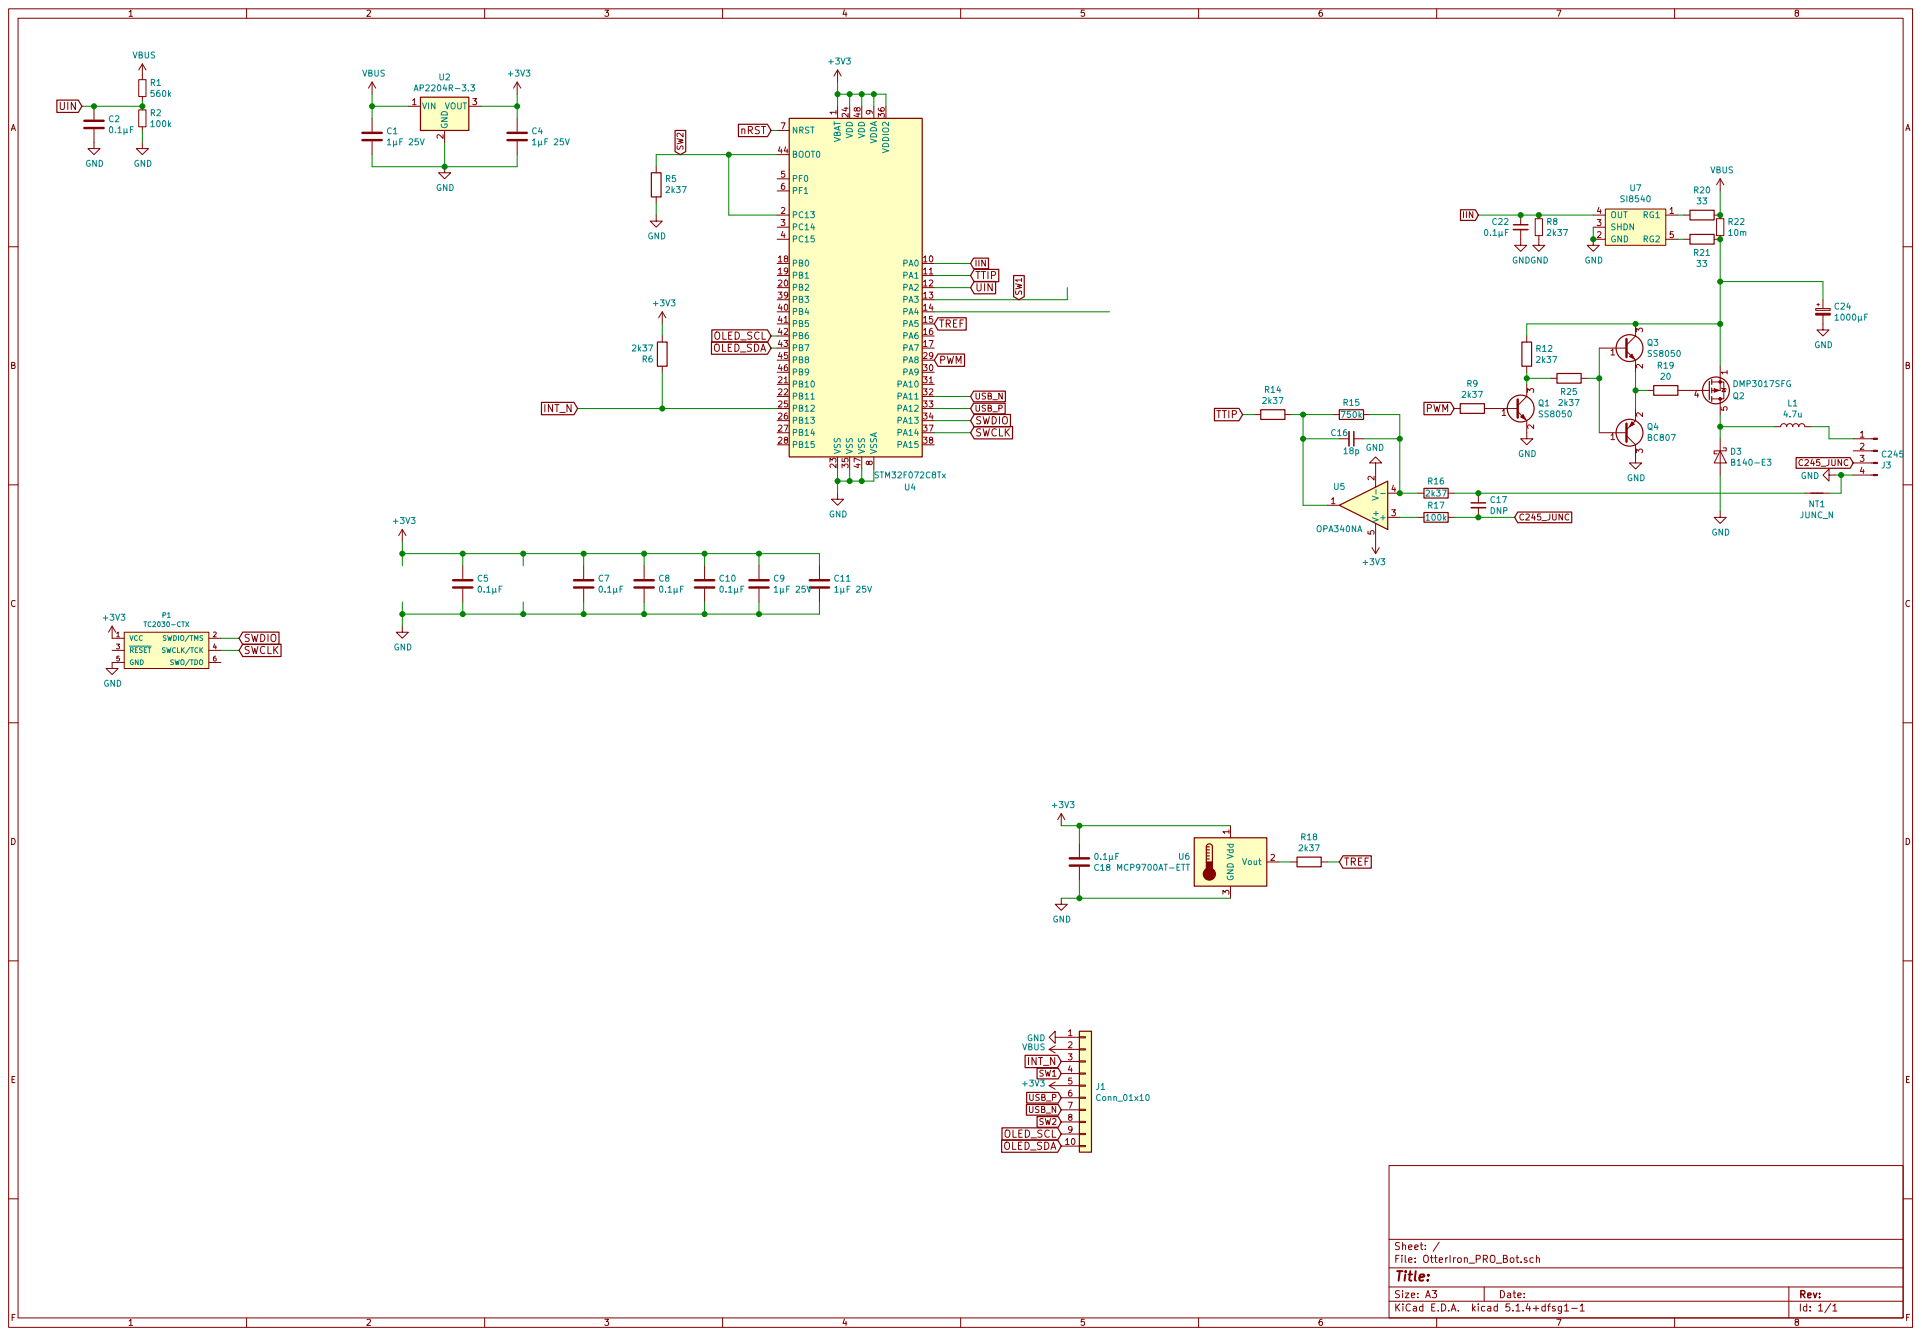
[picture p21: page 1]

9 VDDIO2 36 VSS 23 VSS 35 VSS 47 VSSA

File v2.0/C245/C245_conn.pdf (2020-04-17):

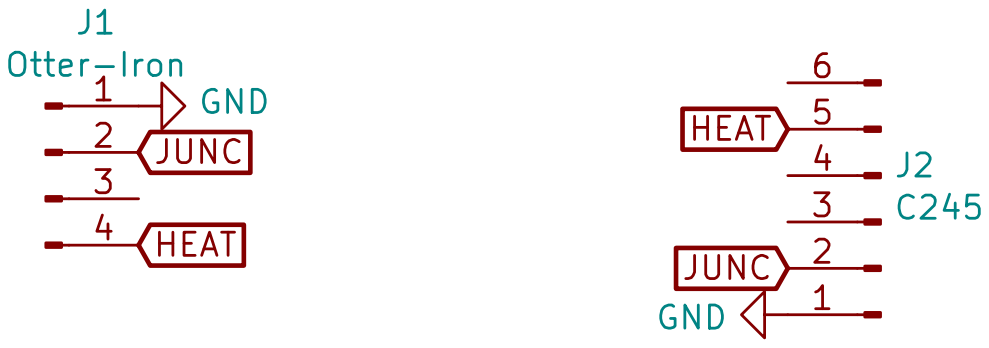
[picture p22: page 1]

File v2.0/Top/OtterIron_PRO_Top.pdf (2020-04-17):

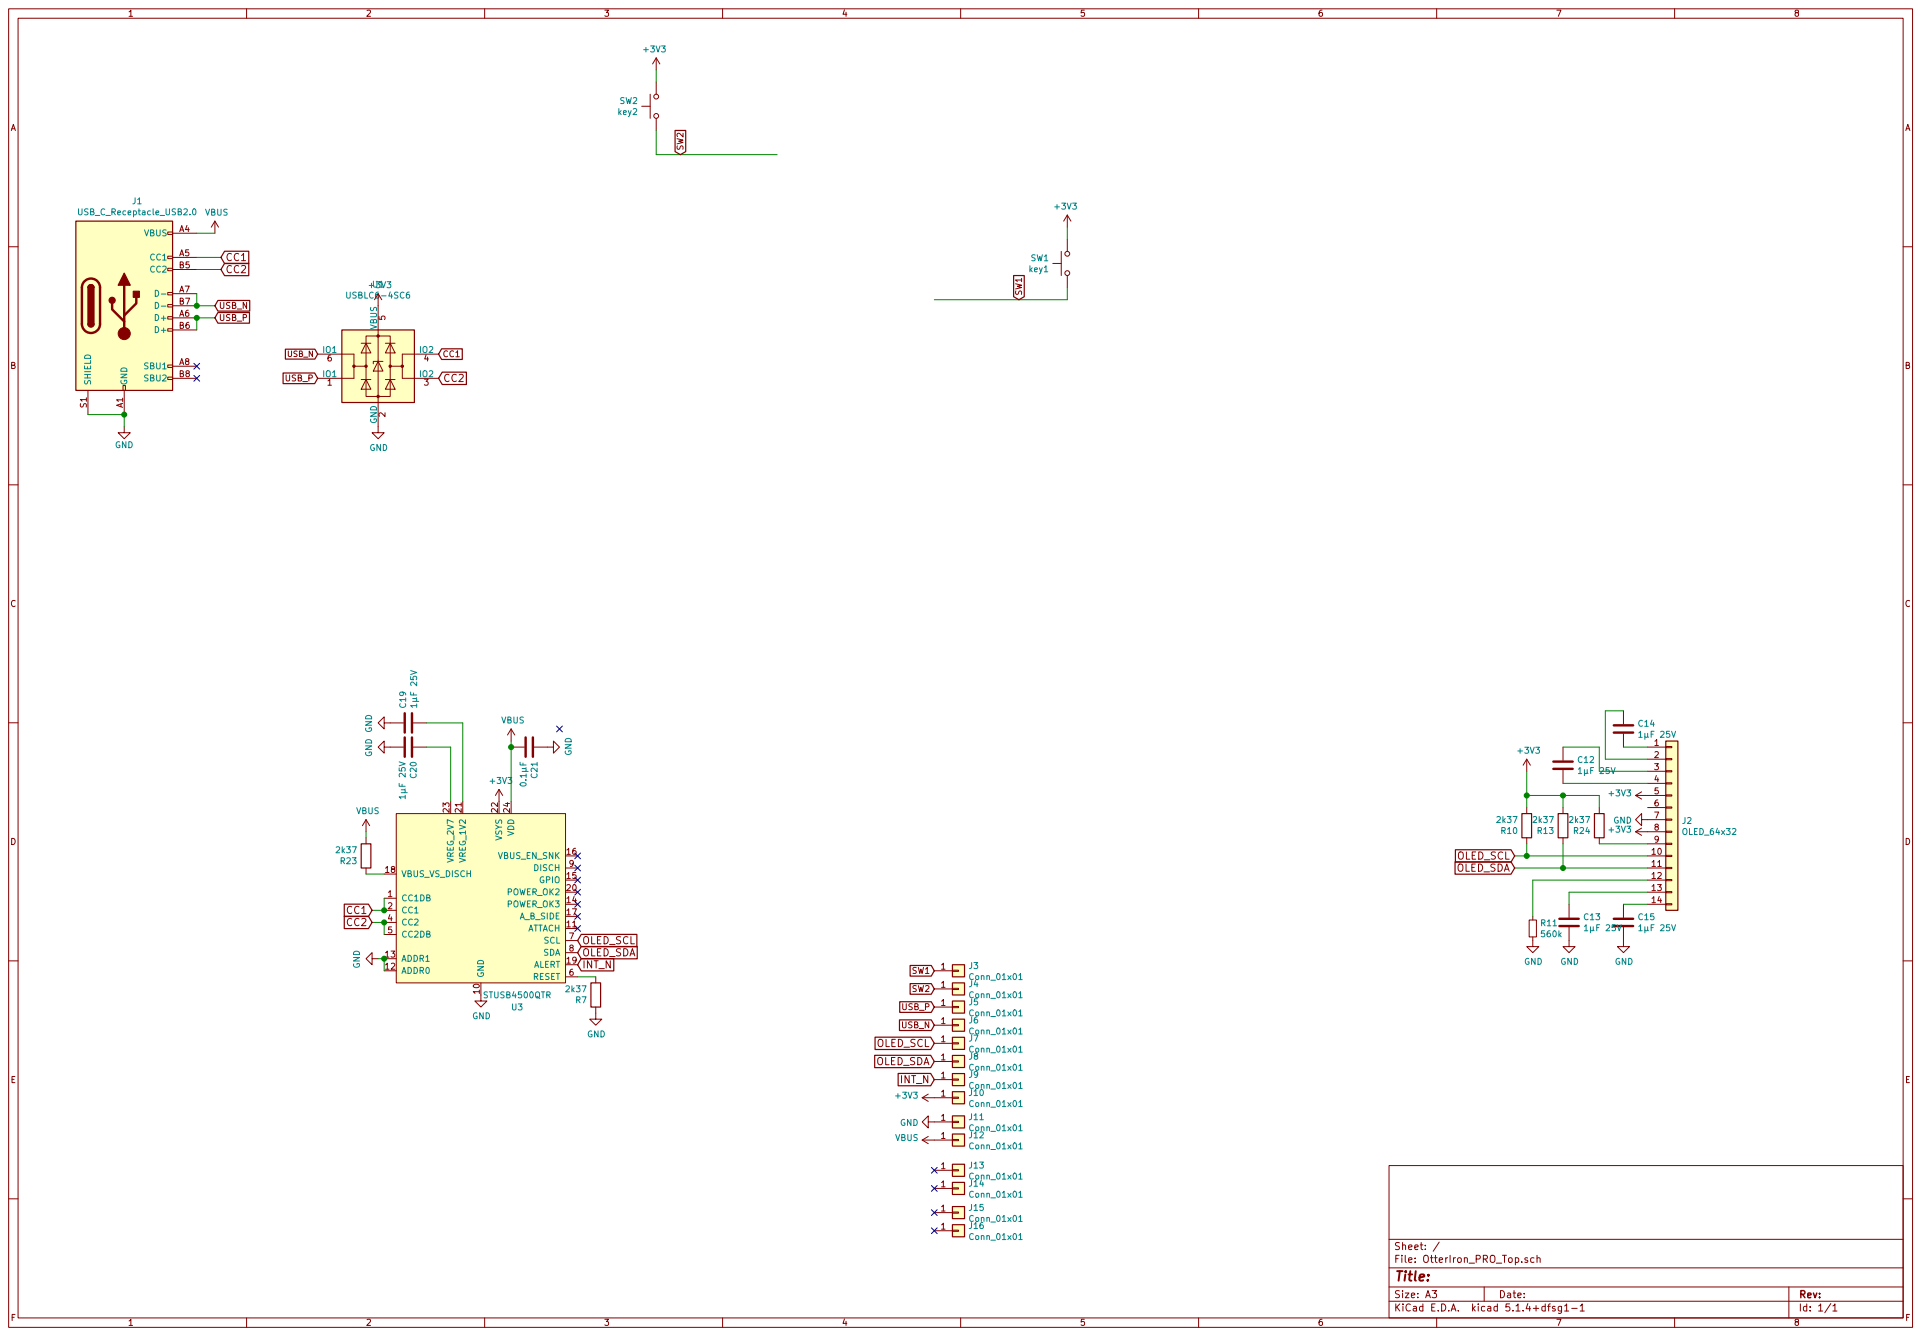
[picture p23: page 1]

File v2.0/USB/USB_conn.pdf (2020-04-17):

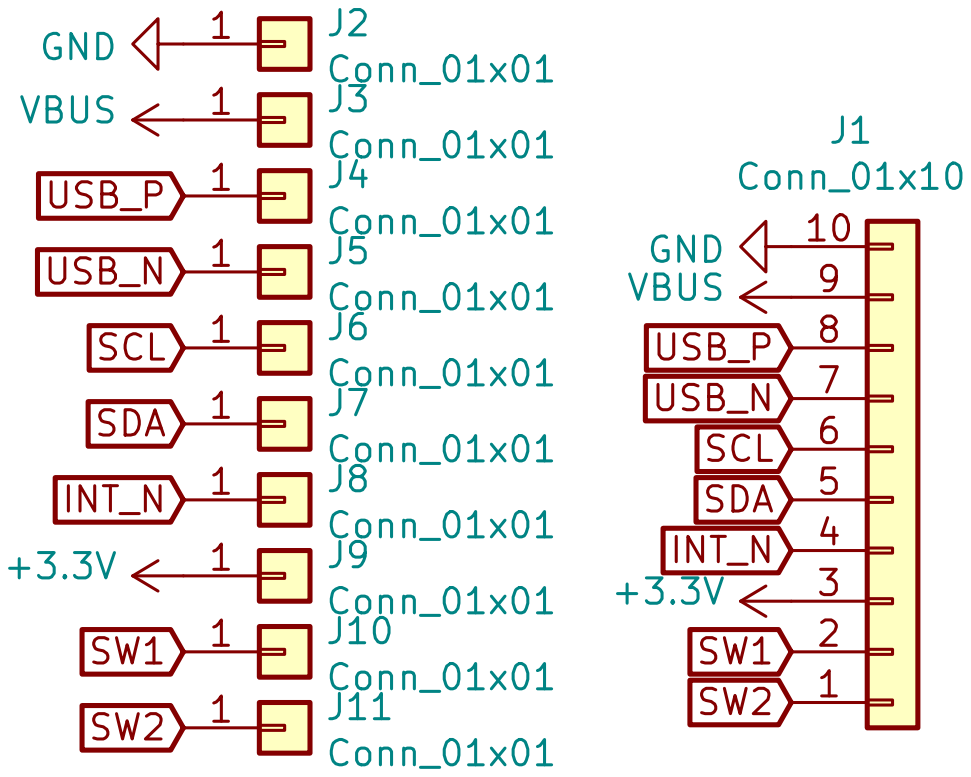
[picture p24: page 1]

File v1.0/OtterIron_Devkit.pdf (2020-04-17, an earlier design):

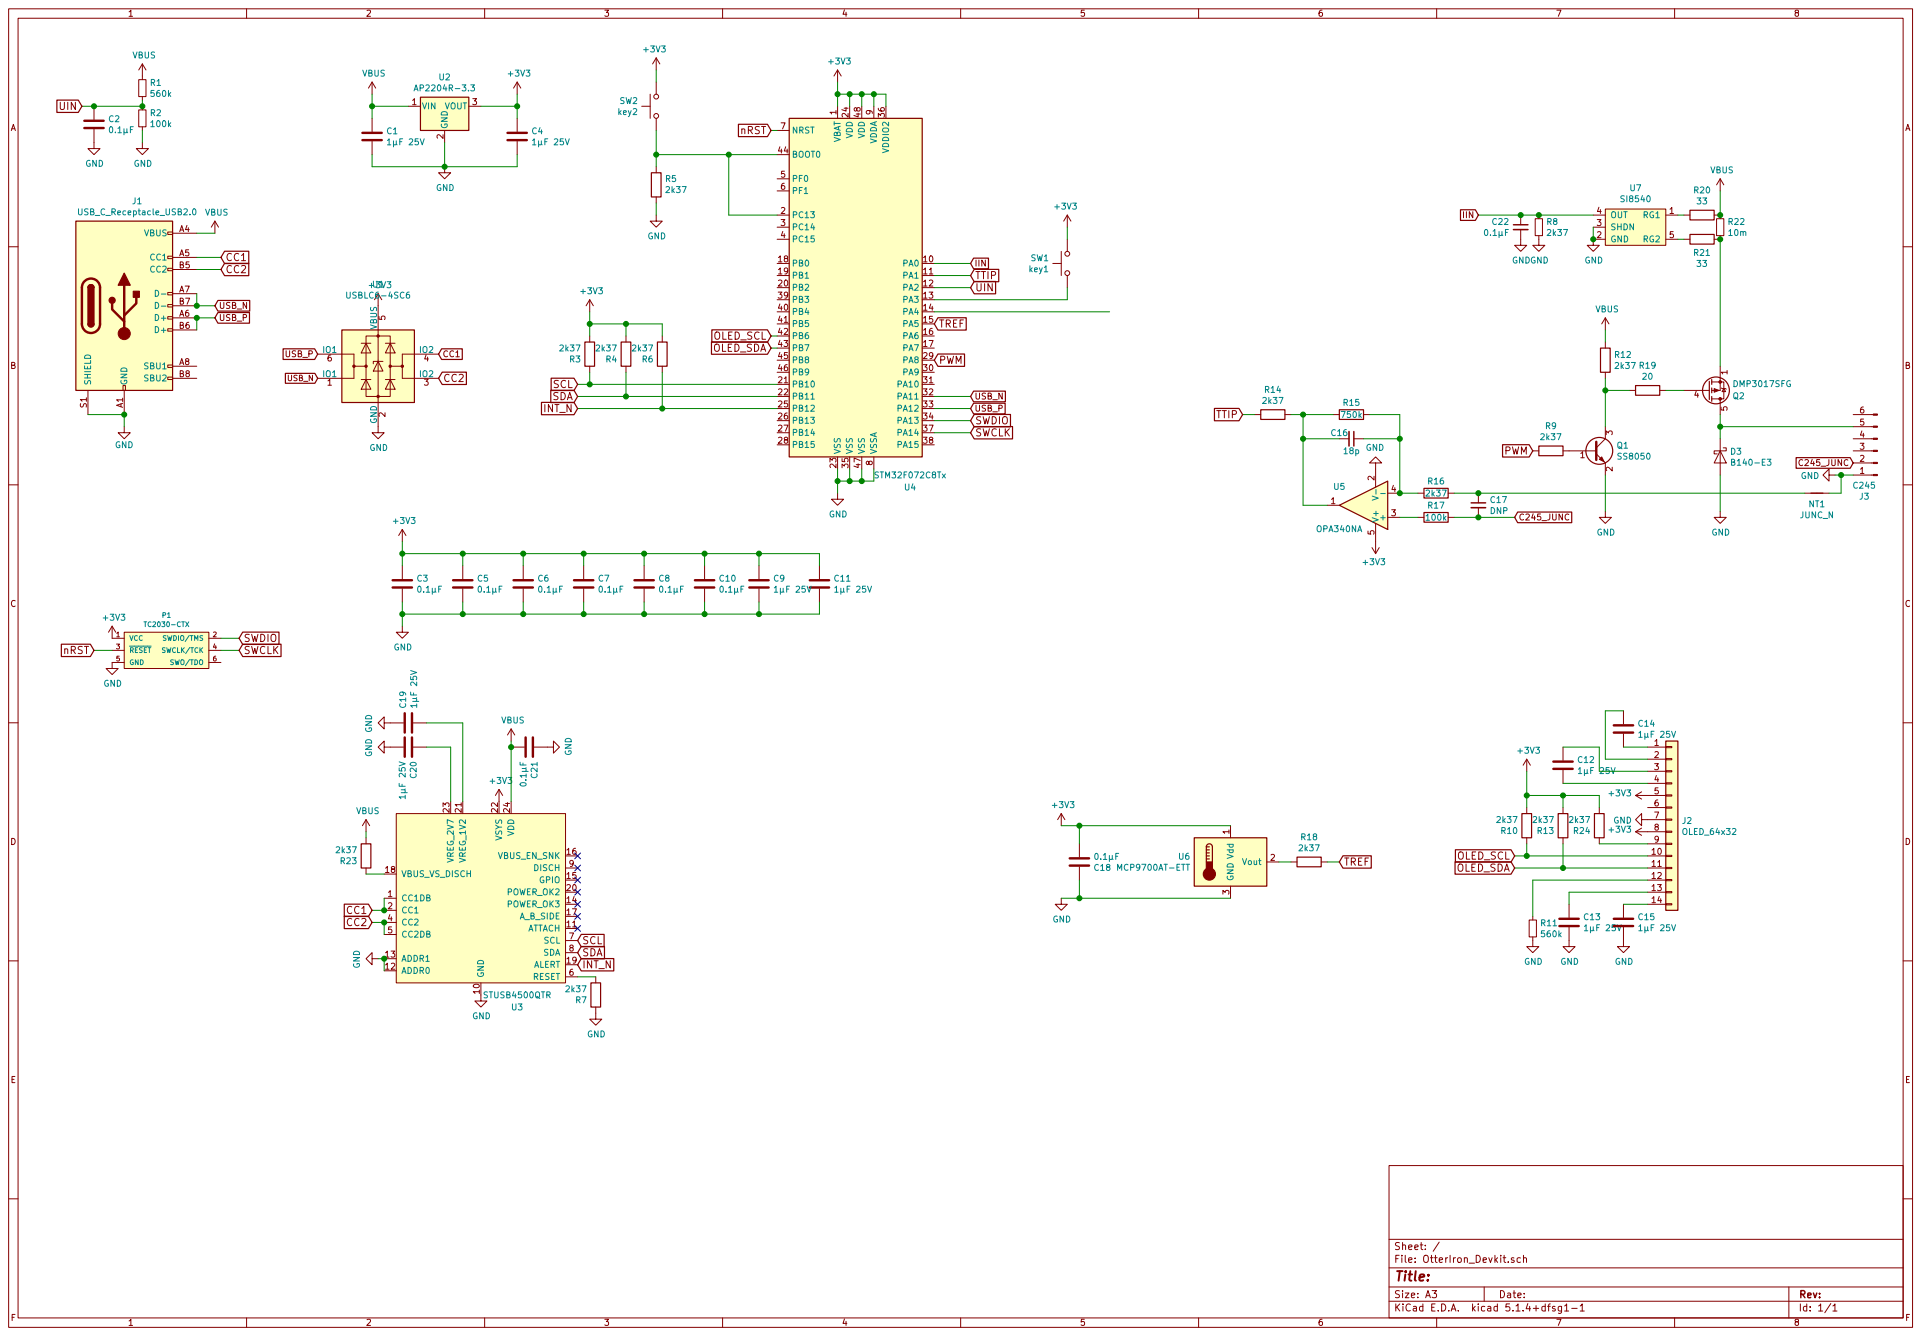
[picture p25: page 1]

9 VDDIO2 36 VSS 23 VSS 35 VSS 47 VSSA

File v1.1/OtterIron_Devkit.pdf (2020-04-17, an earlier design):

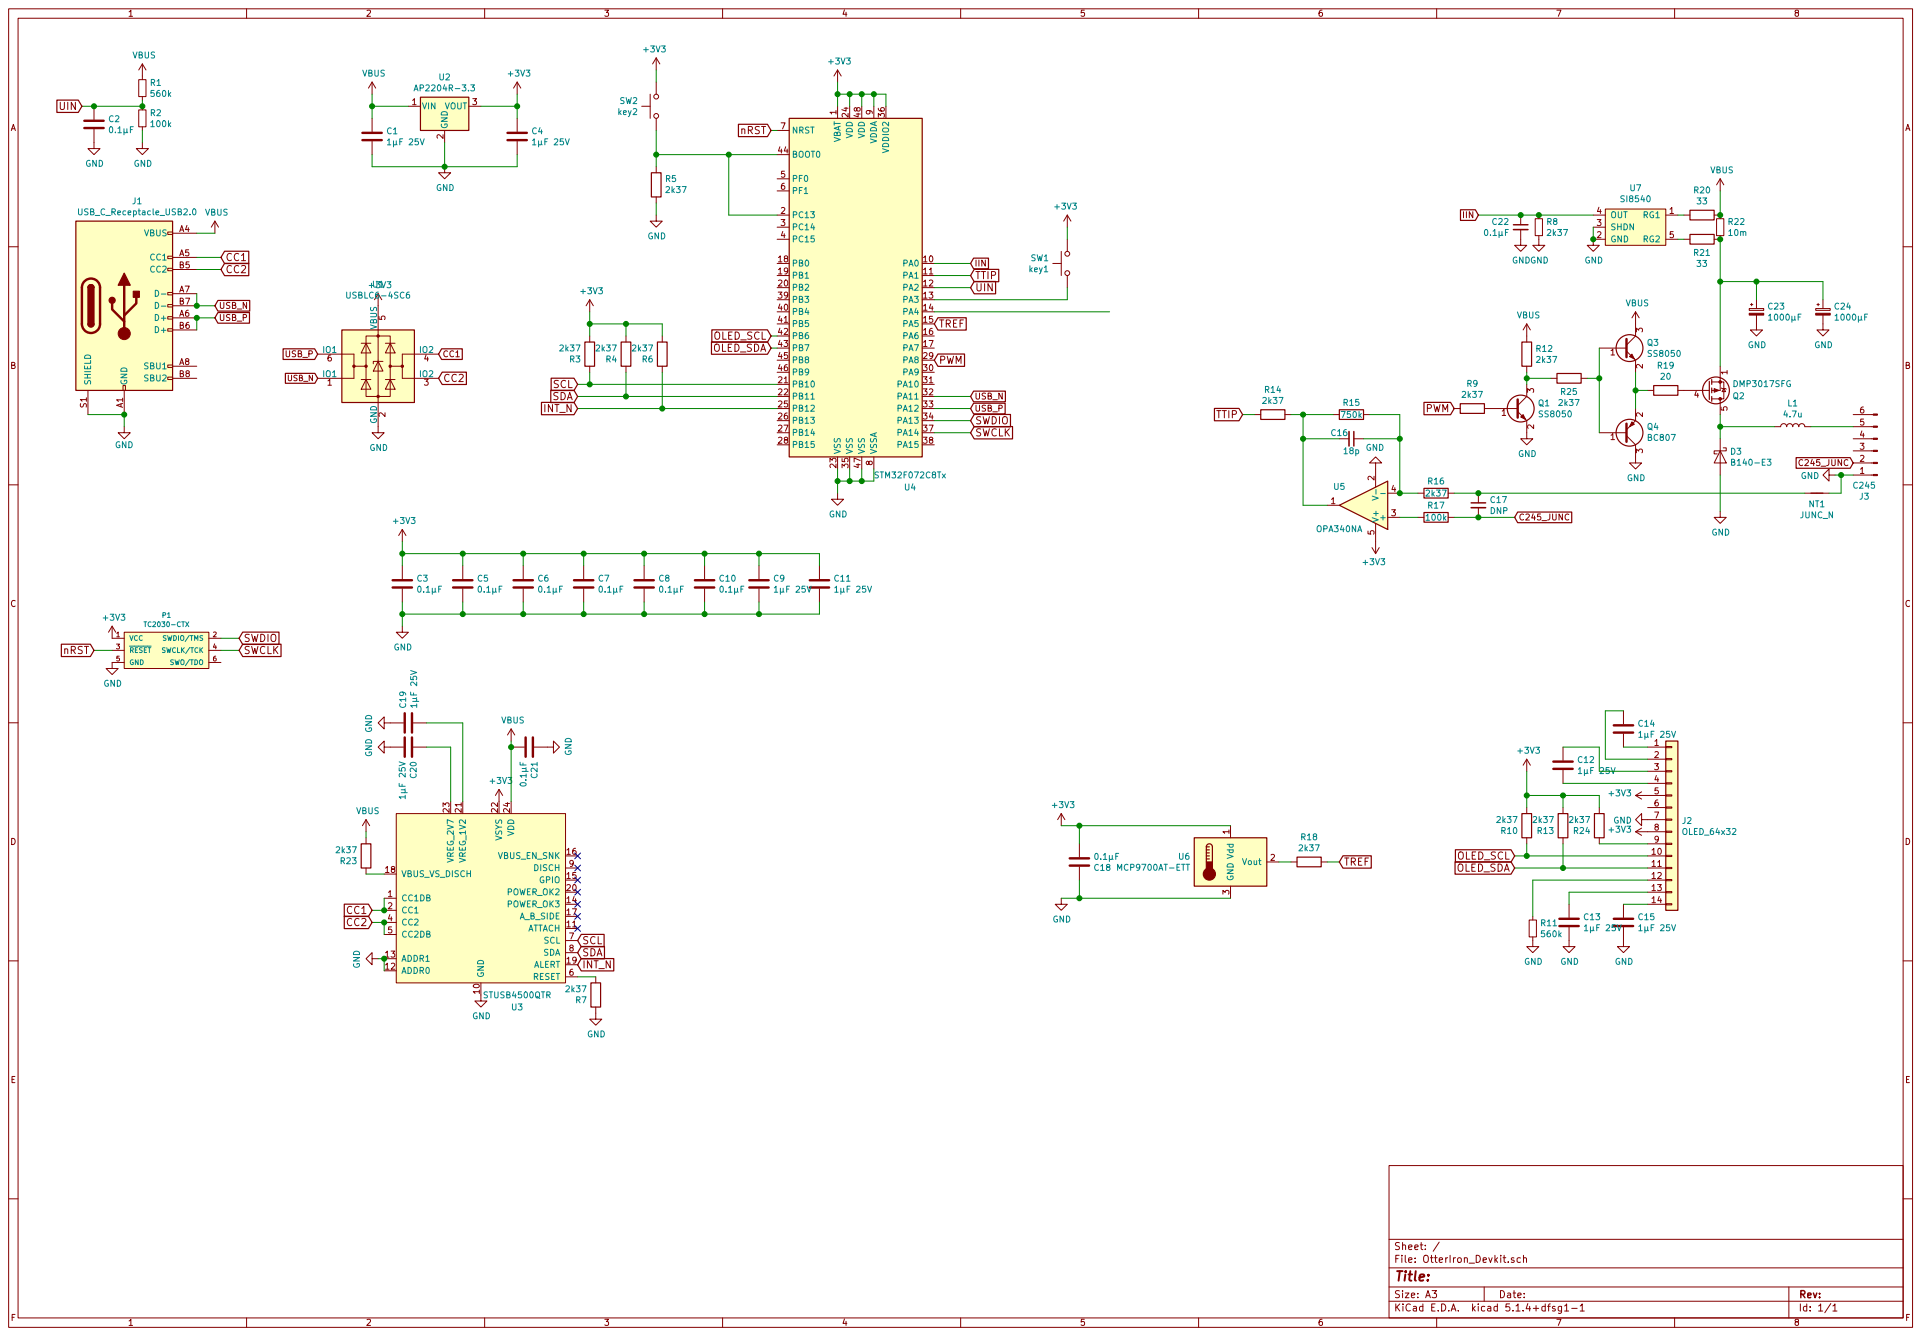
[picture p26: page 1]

9 VDDIO2 36 VSS 23 VSS 35 VSS 47 VSSA

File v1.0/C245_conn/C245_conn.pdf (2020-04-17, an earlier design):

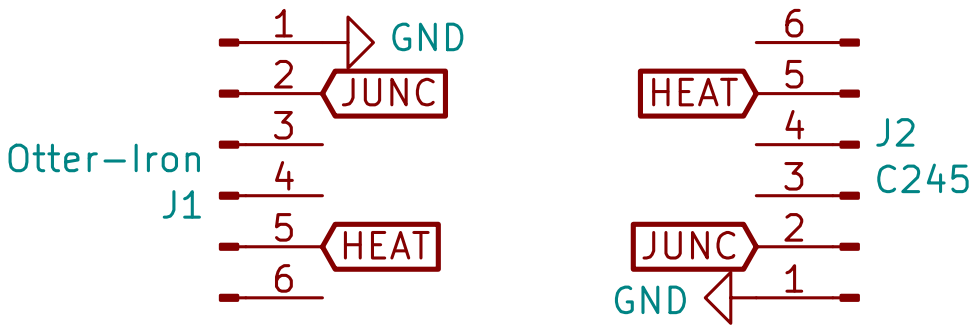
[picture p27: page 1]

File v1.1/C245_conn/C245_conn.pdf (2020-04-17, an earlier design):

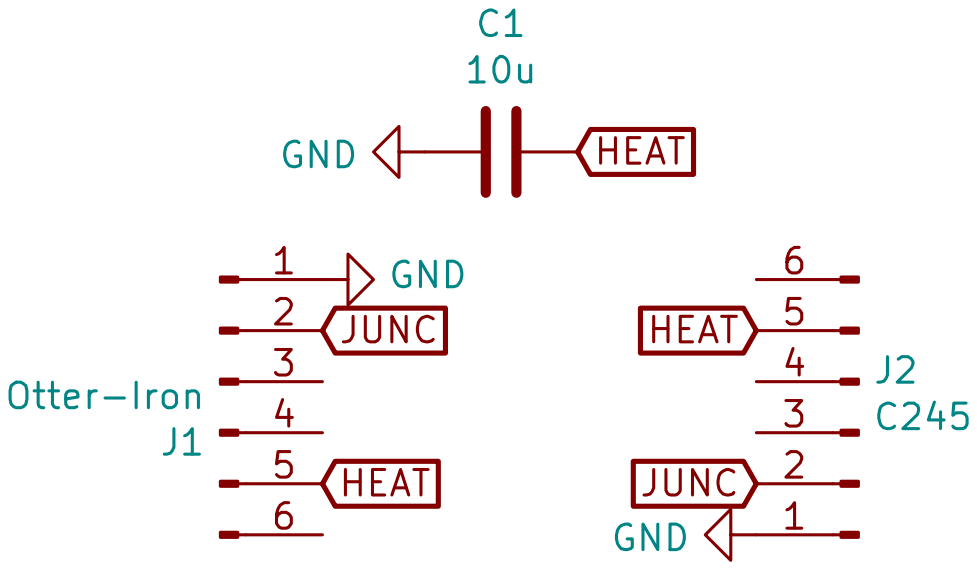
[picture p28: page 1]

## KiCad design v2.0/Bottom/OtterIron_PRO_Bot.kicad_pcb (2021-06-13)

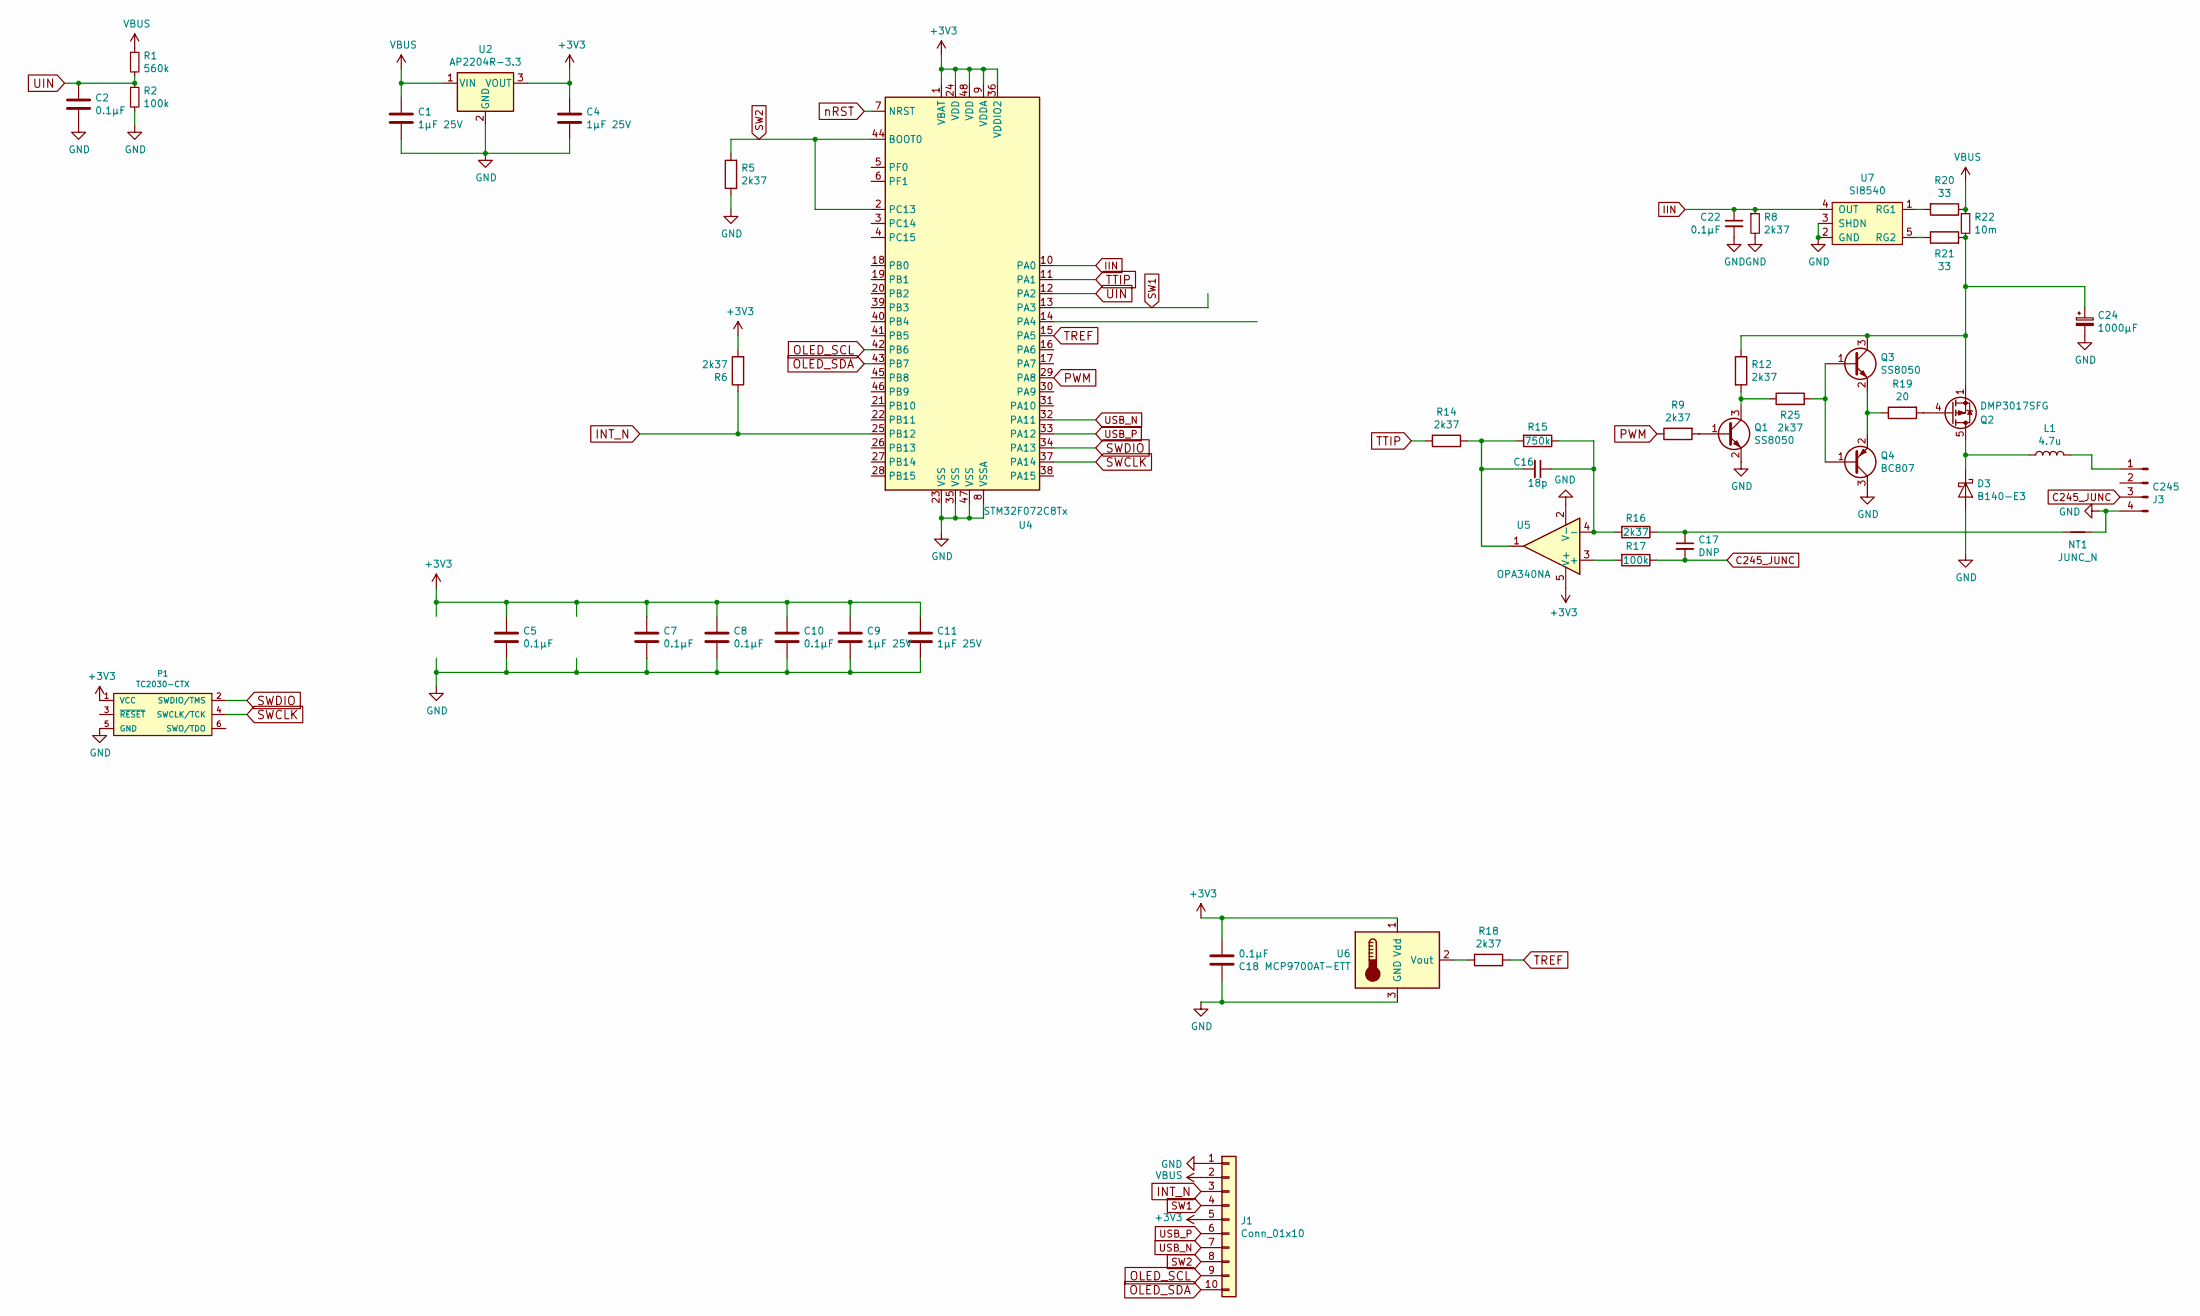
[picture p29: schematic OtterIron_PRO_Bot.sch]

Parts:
C1, C4, C9, C11: 1μF 25V; C_0603
C2, C5, C7, C8, C10, C18, C22: 0.1μF; C_0402
C16: 18p; C_0402
C17: DNP; C_0402
C24: 1000µF; CP_Radial_D10.0mm_P5.00mm_flat
D3: B140-E3; D_SOD-123F
J1: Conn_01x10; PinHeader_1x10_P2.00mm_Horizontal
J3: C245; PinHeader_1x04_P2.54mm_Horizontal
L1: 4.7u; L_Taiyo-Yuden_NR-60xx
NT1: JUNC_N; NetTie-2_SMD_Pad0.5mm
P1: TC2030-CTX; TC2030
Q1, Q3: SS8050; SOT-23
Q2: DMP3017SFG; Diodes_PowerDI3333-8
Q4: BC807; SOT-23
R1: 560k; R_0402
R2, R17: 100k; R_0402
R5, R6, R8, R9, R12, R14, R16, R18, R25: 2k37; R_0402
R15: 750k; R_0402
R19: 20; R_0603
R20, R21: 33; R_0402
R22: 10m; R_0805
U2: AP2204R-3.3; SOT-89-3
U4: STM32F072C8Tx; LQFP-48_7x7mm_P0.5mm
U5: OPA340NA; SOT-23-5
U6: MCP9700AT-ETT; SOT-23
U7: SI8540; SOT-23-5

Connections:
+3V3: C4.1, C5.1, C7.1, C8.1, C9.1, C10.1, C11.1, C18.1, J1.5, P1.1 (VCC), R6.2, U2.3 (VOUT), U4.1 (VBAT), U4.9 (VDDA), U4.24 (VDD), U4.36 (VDDIO2), U4.48 (VDD), U5.5 (V+), U6.1 (Vdd)
C245_JUNC: C17.2, J3.3, R17.1
GND: C1.2, C2.2, C4.2, C5.2, C7.2, C8.2, C9.2, C10.2, C11.2, C18.2, C22.2, C24.2, D3.2 (A), J1.1, J3.4, NT1.2, P1.5 (GND), Q1.2 (E), Q4.3 (C), R2.2, R5.1, R8.2, U2.2 (GND), U4.8 (VSSA), U4.23 (VSS), U4.35 (VSS), U4.47 (VSS), U5.2 (V-), U6.3 (GND), U7.2 (GND), U7.3 (SHDN)
IIN: C22.1, R8.1, U4.10 (PA0), U7.4 (OUT)
INT_N: J1.3, R6.1, U4.25 (PB12)
unnamed: C16.1, R15.1, R16.2, U5.4 (-)
unnamed: C16.2, R14.1, R15.2, U5.1
unnamed: C17.1, NT1.1, R16.1
unnamed: C24.1, Q2.1 (S), Q2.2 (S), Q2.3 (S), Q3.3 (C), R12.1, R21.2, R22.2
unnamed 9: D3.1 (K), L1.1, Q2.5 (D); also elsewhere on the board
unnamed 10: J3.1, L1.2; also elsewhere on the board
unnamed: Q1.1 (B), R9.2
unnamed: Q1.3 (C), R12.2, R25.1
unnamed: Q2.4 (G), R19.2
unnamed: Q3.1 (B), Q4.1 (B), R25.2
unnamed: Q3.2 (E), Q4.2 (E), R19.1
unnamed: R17.2, U5.3 (+)
unnamed: R18.2, U6.2 (Vout)
unnamed: R20.2, U7.1 (RG1)
unnamed: R21.1, U7.5 (RG2)
OLED_SCL: J1.9, U4.42 (PB6)
OLED_SDA: J1.10, U4.43 (PB7)
PWM: R9.1, U4.29 (PA8)
SW1: J1.4, U4.13 (PA3)
SW2: J1.8, R5.2, U4.2 (PC13), U4.44 (BOOT0)
SWCLK: P1.4 (SWCLK/TCK), U4.37 (PA14)
SWDIO: P1.2 (SWDIO/TMS), U4.34 (PA13)
TREF: R18.1, U4.15 (PA5)
TTIP: R14.2, U4.11 (PA1)
UIN: C2.1, R1.2, R2.1, U4.12 (PA2)
USB_N: J1.7, U4.32 (PA11)
USB_P: J1.6, U4.33 (PA12)
VBUS: C1.1, J1.2, R1.1, R20.1, R22.1, U2.1 (VIN)
nRST: U4.7 (NRST)

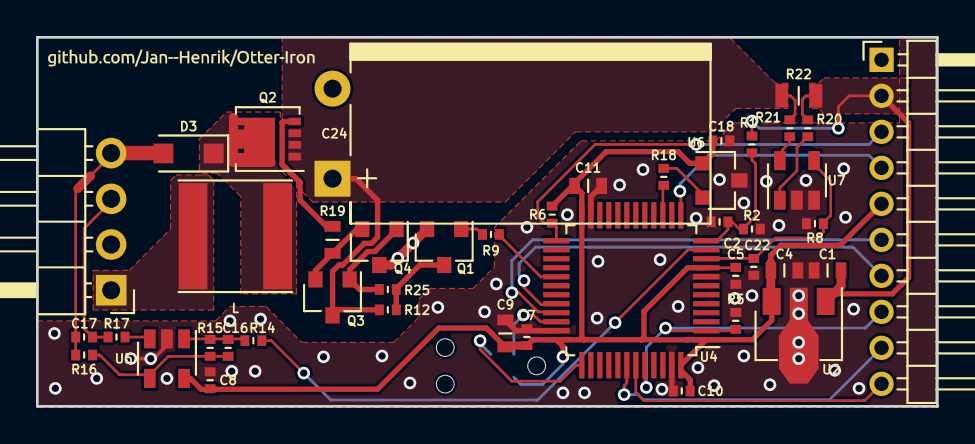
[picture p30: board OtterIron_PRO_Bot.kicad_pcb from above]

Board: 2 copper layers, 50.0 x 20.5 mm, 46 parts (1 on the bottom side), 33 nets.

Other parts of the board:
L: 4.7u; L_Taiyo-Yuden_NR-60xx

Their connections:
unnamed 9: L.1; also elsewhere on the board
unnamed 10: L.2; also elsewhere on the board

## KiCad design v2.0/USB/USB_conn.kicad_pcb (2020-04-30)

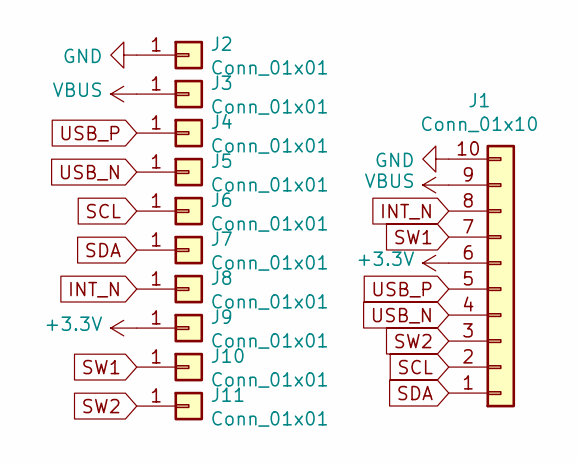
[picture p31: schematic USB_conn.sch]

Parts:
J1: Conn_01x10; PinHeader_1x10_P2.00mm_Vertical
J2, J3: Conn_01x01; pad_1.5_3
J4, J5: Conn_01x01; pad_0.75_3
J6, J7, J8, J9, J10, J11: Conn_01x01; pad_1_2

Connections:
+3V3: J1.6, J9.1
GND: J1.10, J2.1
INT_N: J1.8, J8.1
SCL: J1.2, J6.1
SDA: J1.1, J7.1
SW1: J1.7, J10.1
SW2: J1.3, J11.1
USB_N: J1.4, J5.1
USB_P: J1.5, J4.1
VBUS: J1.9, J3.1

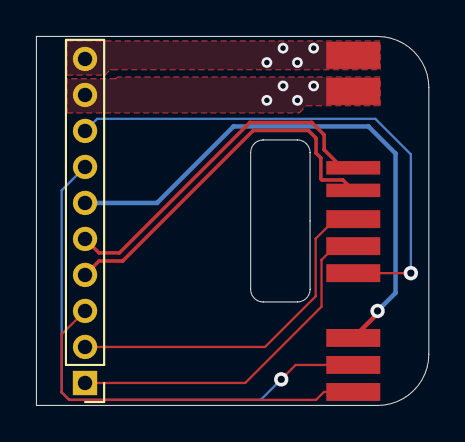
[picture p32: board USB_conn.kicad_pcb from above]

Board: 2 copper layers, 21.8 x 20.5 mm, 11 parts (0 on the bottom side), 10 nets.

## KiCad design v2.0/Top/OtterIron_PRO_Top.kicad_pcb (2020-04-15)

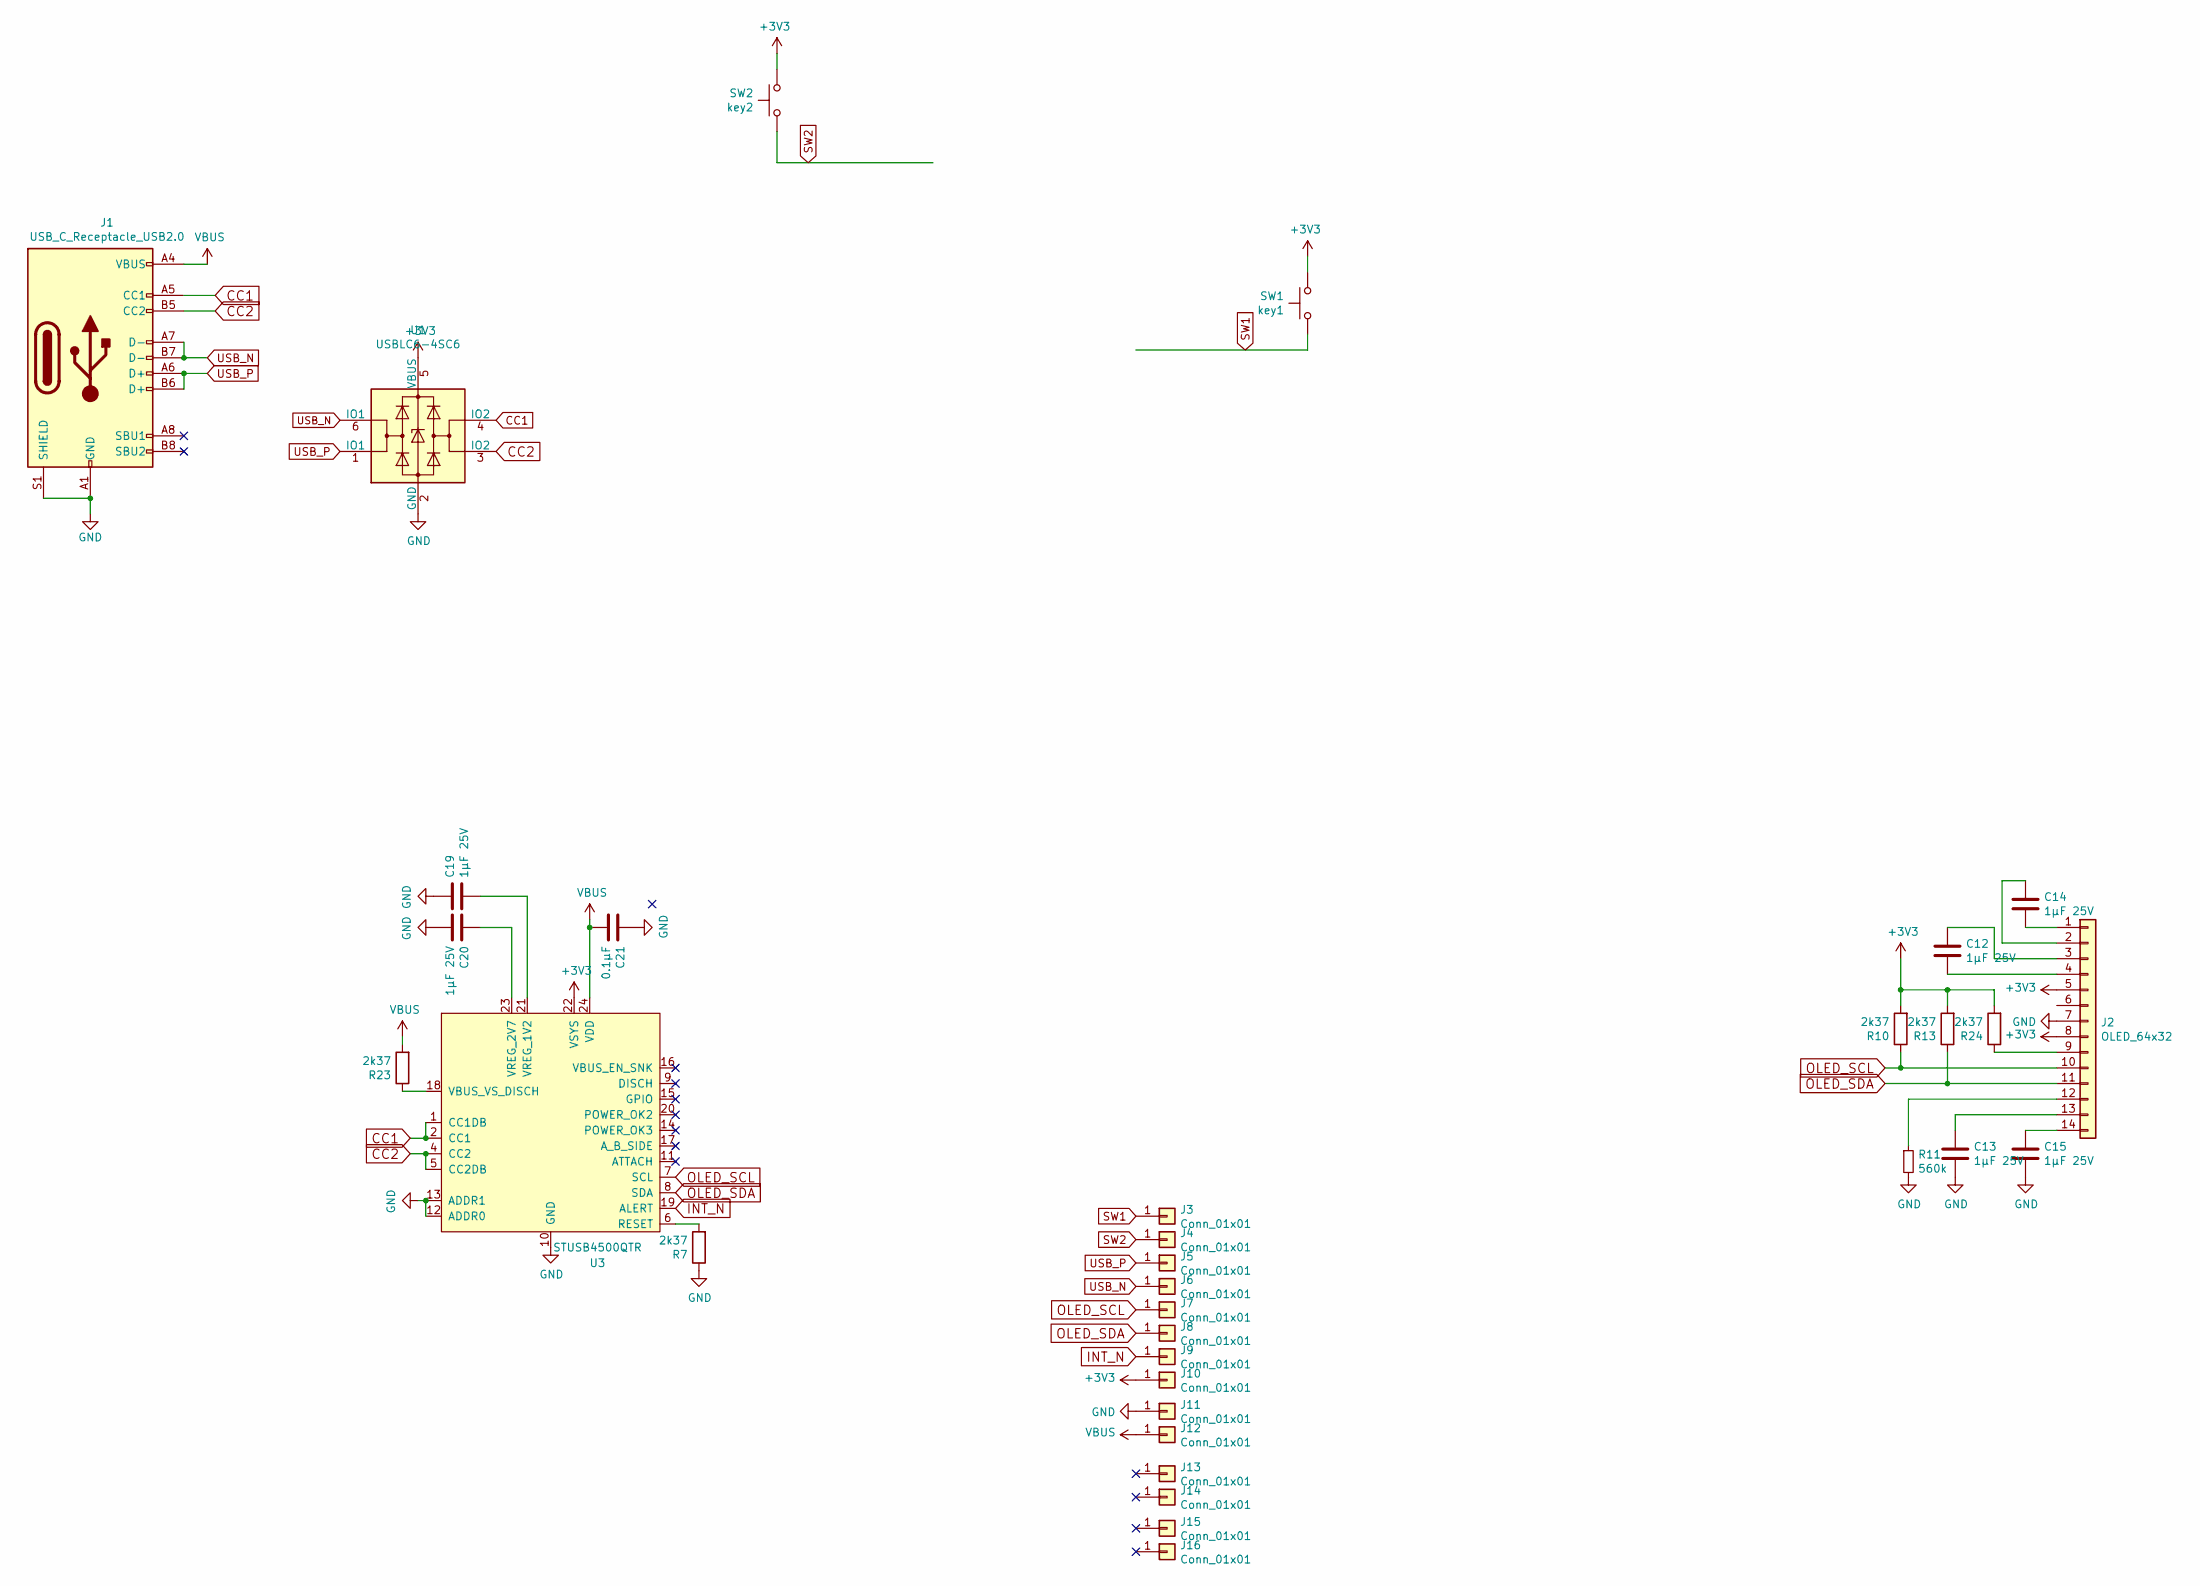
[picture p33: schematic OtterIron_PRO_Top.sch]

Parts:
C12, C13, C14, C15, C19, C20: 1μF 25V; C_0603
C21: 0.1μF; C_0603
J1: USB_C_Receptacle_USB2.0; USB-C 16Pin
J2: OLED_64x32; 0.69OLED
J3, J4, J7, J8, J9, J10: Conn_01x01; pad_1_2
J5, J6: Conn_01x01; pad_0.75_3
J11, J12, J13, J14, J15, J16: Conn_01x01; pad_1.5_3
R7, R10, R13, R23, R24: 2k37; R_0603
R11: 560k; R_0603
SW1: key1; SW_SPST_EVQP7C
SW2: key2; SW_SPST_EVQP7C
U1: USBLC6-4SC6; SOT-23-6
U3: STUSB4500QTR; QFN-24-1EP_4x4mm_P0.5mm_EP2.7x2.7mm

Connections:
+3V3: J2.5, J2.8, J10.1, R10.2, R13.2, R24.2, SW1.1, SW2.1, U1.5 (VBUS), U3.22 (VSYS)
CC1: J1.A5 (CC1), U1.4 (IO2), U3.1 (CC1DB), U3.2 (CC1)
CC2: J1.B5 (CC2), U1.3 (IO2), U3.4 (CC2), U3.5 (CC2DB)
GND: C13.2, C15.2, C19.1, C20.2, C21.1, J1.A1 (GND), J1.A12 (GND), J1.B1 (GND), J1.B12 (GND), J1.S1 (SHIELD), J2.7, J11.1, R7.1, R11.2, U1.2 (GND), U3.10 (GND), U3.12 (ADDR0), U3.13 (ADDR1), U3.25 (GND)
INT_N: J9.1, U3.19 (ALERT)
unnamed: C12.1, J2.3
unnamed: C12.2, J2.4
unnamed: C13.1, J2.13
unnamed: C14.1, J2.2
unnamed: C14.2, J2.1
unnamed: C15.1, J2.14
unnamed: C19.2, U3.21 (VREG_1V2)
unnamed: C20.1, U3.23 (VREG_2V7)
unnamed: J2.9, R24.1
unnamed: J2.12, R11.1
unnamed: R7.2, U3.6 (RESET)
unnamed: R23.1, U3.18 (VBUS_VS_DISCH)
OLED_SCL: J2.10, J7.1, R10.1, U3.7 (SCL)
OLED_SDA: J2.11, J8.1, R13.1, U3.8 (SDA)
SW1: J3.1, SW1.2
SW2: J4.1, SW2.2
USB_N: J1.A7 (D-), J1.B7 (D-), J6.1, U1.6 (IO1)
USB_P: J1.A6 (D+), J1.B6 (D+), J5.1, U1.1 (IO1)
VBUS: C21.2, J1.A4 (VBUS), J1.A9 (VBUS), J1.B4 (VBUS), J1.B9 (VBUS), J12.1, R23.2, U3.24 (VDD)

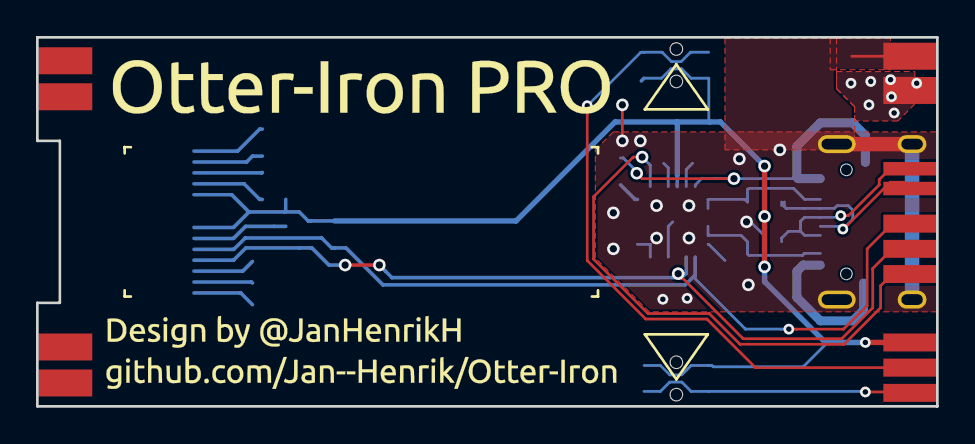
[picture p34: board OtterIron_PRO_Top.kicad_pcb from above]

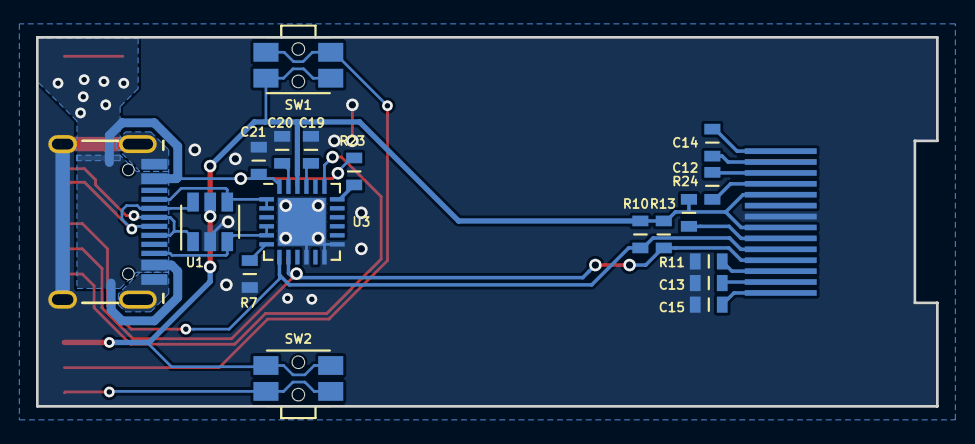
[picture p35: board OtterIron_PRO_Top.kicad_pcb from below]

Board: 2 copper layers, 50.0 x 20.5 mm, 33 parts (19 on the bottom side), 24 nets.

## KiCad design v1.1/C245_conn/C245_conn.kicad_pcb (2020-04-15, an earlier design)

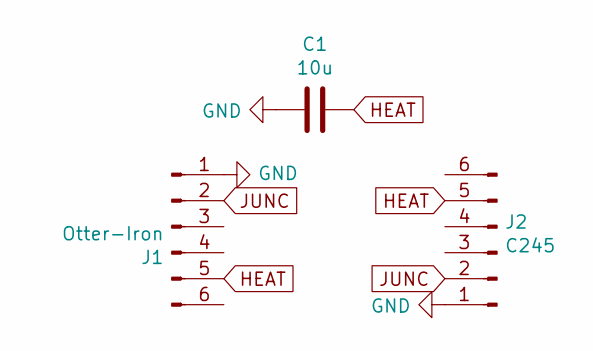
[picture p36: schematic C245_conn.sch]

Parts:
C1: 10u; C_1206_3216Metric
J1: Otter-Iron; PinHeader_1x06_P2.54mm_Vertical
J2: C245; RPC1-12RB-6P(71)

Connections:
GND: C1.2, J1.1, J2.1
HEAT: C1.1, J1.5, J2.5
JUNC: J1.2, J2.2

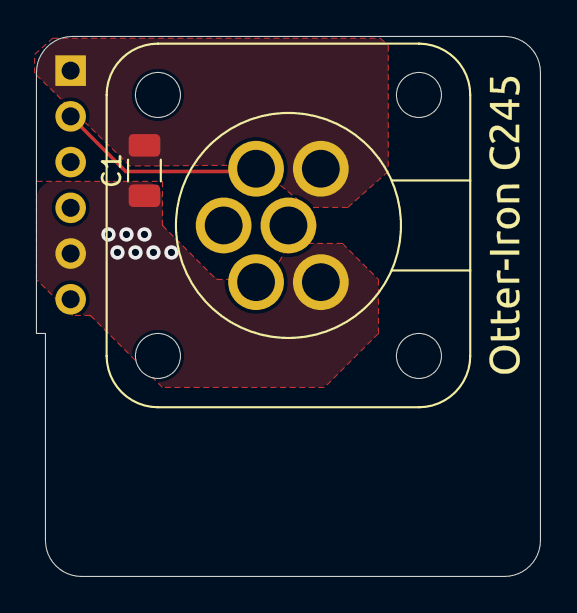
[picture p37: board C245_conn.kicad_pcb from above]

Board: 2 copper layers, 28.0 x 30.0 mm, 3 parts (1 on the bottom side), 3 nets.

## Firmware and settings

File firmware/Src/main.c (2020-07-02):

/*
 * Otter-Iron  -  Stm32f072 based soldering iron.
 * Copyright (C) 2020 Jan Henrik Hemsing
 *
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
 * You should have received a copy of the GNU General Public License along with
 * this program.  If not, see <http://www.gnu.org/licenses/>.
 */

#include <math.h>

#include "main.h"
#include "font.h"
#include "stusb4500.h"

// Enable serial printing via CDC, quite buggy
/* #define ENABLESERIAL */
// Enable Current display, shows up after a few millisecconds instead of temp-target
#define DISPLAYCURRENT
// Enable check of USB PD profile capable before beforing iron
#define CHECKUSBPD

#define FILT(a, b, c) ((a) * (c) + (b) * ((1.0f) - (c)))
#define CLAMP(x, low, high) (((x) > (high)) ? (high) : (((x) < (low)) ? (low) : (x)))

#define TTIP_AVG_FILTER 0.99f
#define DISP_AVG_FILTER 0.9f

#define MIN_DUTY 0
#define MAX_DUTY 2000

#define MIN_VOLTAGE 15.0f
#define MIN_CURRENT 1.0f
uint16_t wduty = 800;

ADC_HandleTypeDef hadc;
DMA_HandleTypeDef hdma_adc;

I2C_HandleTypeDef hi2c1;

TIM_HandleTypeDef htim1;
TIM_HandleTypeDef htim3;

IWDG_HandleTypeDef hiwdg;

USBD_HandleTypeDef USBD_Device;

void SystemClock_Config(void);
static void MX_GPIO_Init(void);
static void MX_ADC_Init(void);
static void MX_DMA_Init(void);
static void MX_I2C1_Init(void);
static void MX_TIM1_Init(void);
static void TIM3_Init(void);
static void MX_IWDG_Init(void);

void reg(void);
void disp_init(void);
void refresh(void);
void clear_screen(void);
void set_screen(void);
void write_pixel(int16_t x, int16_t y, uint8_t color);
void draw_char(unsigned char  c, uint8_t x, uint8_t y, uint8_t brightness);
void draw_string(const unsigned char * str, uint8_t x, uint8_t y, uint8_t brightness);
void draw_v_line(int16_t x, int16_t y, uint16_t h, uint8_t color);
void USB_printfloat(float _buf);

struct status_t{
  float ttip;
  float ttipavg;
  float uin;
  float iin;
  float iinavg;
  float imax;
  float tref;
  uint8_t writeFlash;
  uint8_t button[2];
  float drawlineavg;
#ifdef DISPLAYCURRENT
  uint8_t timeout;
#endif
  uint8_t active;
  uint8_t pdo;
}s = {.writeFlash = 0, .imax = 1.5f}; // imax will be updated enumerated USB PD profile

struct reg_t{
  float target;
  float error;
  float ierror;
  float imax;
  float derror;
  int16_t duty;
  float cycletime;
  float Kp;
  float Ki;
  float deadband;
}r = {.Kp = 0.5f,.Ki = 1.0f,.cycletime = 0.0000725f,.imax=10.0f,.target=220.0f,.deadband=15.0f};

struct tipcal_t{
  float offset;
  float coefficient;
} tipcal = {.offset = 120, .coefficient = 92};

static uint16_t ADC_raw[4];

extern uint8_t UserTxBuffer[APP_TX_DATA_SIZE];/* Received Data over UART (CDC interface) are stored in this buffer */
uint32_t sendDataUSB;

const unsigned char* dfu_string = (unsigned char*) "dfudfudfudfudfu";
const unsigned char* otter_string = (unsigned char*) "Otter-Iron";
const unsigned char* by_string = (unsigned char*) "by Jan Henrik";

int main(void)
{
  HAL_Init();

  SystemClock_Config();

  MX_GPIO_Init();
  MX_DMA_Init();
  MX_ADC_Init();
  MX_I2C1_Init();
  MX_TIM1_Init();
  TIM3_Init();

  // setup STUSB4500 PD requests before starting controller IT
  stusb_update_pdo(1, 5000, 500); // allows comms on standard 5 V
  // 30 W and 80 W - ensures iron is well behaved and enumerates PD profile before drawing it
  stusb_update_pdo(2, 20000, 1500);
  stusb_update_pdo(3, 20000, 4000);
  stusb_set_valid_pdo(3);

  // now display
  HAL_Delay(200);
  disp_init();
  clear_screen();

  // now system
  HAL_TIM_PWM_Start(&htim1, TIM_CHANNEL_1);
  HAL_TIM_OC_Start(&htim1, TIM_CHANNEL_4);

  HAL_ADC_Start_DMA(&hadc, (uint32_t *)ADC_raw, 4);

  //DFU bootloader
  if(HAL_GPIO_ReadPin(GPIOA,B1_Pin) && HAL_GPIO_ReadPin(GPIOA,B2_Pin)){
    draw_string(dfu_string, 1, 1 ,1);
    draw_string(dfu_string, 1, 8 ,1);
    refresh();
    HAL_Delay(40);
    *((unsigned long *)0x20003FF0) = 0xDEADBEEF;
    NVIC_SystemReset();
  } else {
    draw_string(otter_string, 15, 1 ,1);
    draw_string(by_string, 10, 9 ,1);
    refresh();
    HAL_Delay(500);
#ifdef ENABLESERIAL
    //start USB CDC
    USBD_Init(&USBD_Device, &VCP_Desc, 0);
    USBD_RegisterClass(&USBD_Device, &USBD_CDC);
    USBD_CDC_RegisterInterface(&USBD_Device, &USBD_CDC_fops);
    HAL_TIM_Base_Start_IT(&htim3);
    USBD_Start(&USBD_Device);
#endif
#ifdef DISPLAYCURRENT
      s.timeout = 20;
#endif
#ifdef CHECKUSBPD
    unsigned char line1[22];
    unsigned char line2[22];
    STUSB_GEN1S_RDO_REG_STATUS_RegTypeDef Nego_RDO;

    if (stusb_read_rdo(&Nego_RDO) == HAL_OK) {
      s.imax = (float) Nego_RDO.b.MaxCurrent / 100.0;
      s.pdo = Nego_RDO.b.Object_Pos;
    } else {
      s.pdo = 0;
    }

    if (s.pdo > 0) {
      sprintf((char * restrict) line1, "PD %s %1d", s.pdo > 3 ? "Adjust" : "Profile", s.pdo);
      sprintf((char * restrict) line2, "%1d.%1d A %2d W", (uint16_t)s.imax,(uint16_t)((s.imax-(uint16_t)s.imax)*10.0f), (uint16_t) (ceil(s.uin) * s.imax));
    } else {
      sprintf((char * restrict) line1, "USB !USB-PD");
      sprintf((char * restrict) line2, "Iron Disabled");
    }
    clear_screen();
    draw_string(line1, 10, 1 ,1);
    draw_string(line2, 10, 9 ,1);
    refresh();
    HAL_Delay(1000);
#endif
  }

  HAL_Delay(1000);
  MX_IWDG_Init();

  r.target = *((uint16_t *) 0x0800e400);
  if (r.target >= 400) r.target = 220;  //initial temp set

  while (1)
  {
    HAL_Delay(50);

    //UI
    s.button[1] = HAL_GPIO_ReadPin(GPIOA,B1_Pin);
    s.button[0] = HAL_GPIO_ReadPin(GPIOA,B2_Pin) | HAL_GPIO_ReadPin(GPIOC, B1_1_Pin);

    if(s.button[0] == 1){
      r.target -= 5;
      s.writeFlash = 1;
      HAL_Delay(40);
    }

    if(s.button[1] == 1){
      r.target += 5;
      s.writeFlash = 1;
      HAL_Delay(40);
    }

    r.target = CLAMP(r.target, 20, 400);

    if(s.writeFlash == 1){
      HAL_FLASH_Unlock();
      FLASH->CR |= FLASH_CR_PER;
      FLASH->AR = 0x0800e400;
      FLASH->CR |= FLASH_CR_STRT;
      while ((FLASH->SR & FLASH_SR_BSY) != 0){}
      if ((FLASH->SR & FLASH_SR_EOP) != 0){
        FLASH->SR |= FLASH_SR_EOP;
        FLASH->CR &= ~FLASH_CR_PER;
        HAL_FLASH_Program(FLASH_TYPEPROGRAM_HALFWORD, 0x0800e400, (uint16_t)r.target);
        HAL_FLASH_Lock();
        s.writeFlash = 0;
      }
      #ifdef DISPLAYCURRENT
            s.timeout = 12;
      #endif
    }

#ifdef ENABLESERIAL
    // send temperature via USB CDC
    USB_printfloat(r.error);
#endif

    //super shitty display code
    unsigned char str1[14] = "          ";
    unsigned char str2[14] = "          ";
    unsigned char str3[14] = "          ";
    unsigned char str4[14] = "          ";
    sprintf((char * restrict) str1, "%d C   ", (uint16_t)r.target);
    sprintf((char * restrict) str2, "%d.%d C", (uint16_t)s.ttipavg,(uint16_t)((s.ttipavg-(uint16_t)s.ttipavg)*10.0f));
    sprintf((char * restrict) str3, "%d.%d V", (uint16_t)s.uin,(uint16_t)((s.uin-(uint16_t)s.uin)*10.0f));
    sprintf((char * restrict) str4, "%d.%d A", (uint16_t)s.iinavg,(uint16_t)((s.iinavg-(uint16_t)s.iinavg)*10.0f));

    clear_screen();
    draw_string(str1, 10, 1 ,1);
    draw_string(str2, 10, 9 ,1);
    draw_string(str3, 60, 1 ,1);
#ifdef DISPLAYCURRENT
    if(s.timeout == 0){
      draw_string(str4, 10, 1 ,1);
    } else {
      s.timeout--;
    }
#endif
    s.iinavg = (s.iinavg * DISP_AVG_FILTER) + (s.iin*(1.0-DISP_AVG_FILTER));

    if (s.active) {
      s.drawlineavg = (s.drawlineavg * DISP_AVG_FILTER) + (CLAMP(r.error*3.0f,0,30)*(1.0-DISP_AVG_FILTER));
      for(uint16_t i = 0; i <= (int)s.drawlineavg; i++){
        draw_v_line(60+i, 8, 8, 1);
      }
    } else {
      draw_string((const unsigned char*) ((s.pdo > 0) ? "!ACTV" : "!PWRD"), 60, 9, 1);
    }

    refresh();
    HAL_IWDG_Refresh(&hiwdg);
  }
}

uint8_t check_usbpd(void) {
 #ifdef CHECKUSBPD
  return (s.uin >= MIN_VOLTAGE && s.imax >= MIN_CURRENT);
 #else
  return 1;
 #endif
}

// Main PID+two-way controller and ADC readout
void reg(void) {
  static uint16_t count = 0;

  s.tref = ((((float)ADC_raw[3]/4095.0)*3.3)-0.5)/0.01;
  s.ttip = ((ADC_raw[1]-tipcal.offset)*tipcal.coefficient)/1000+s.tref;
  s.uin = ((ADC_raw[2]/4095.0)*3.3)*6.6;
  s.iin = FILT(s.iin, ((ADC_raw[0]/4095.0)*3.3*1.659)/(0.01*(2370/33)), TTIP_AVG_FILTER);

  s.ttipavg = FILT(s.ttipavg, s.ttip, TTIP_AVG_FILTER);

  // check input voltage
  if (check_usbpd()) {
    // Check if within deadband, decide on two-way or PID control
    if(s.ttipavg >= r.target-r.deadband && s.ttipavg <= r.target+r.deadband) {
      r.error = r.target - s.ttipavg;
      r.ierror = r.ierror + (r.error*r.cycletime);
      r.ierror = CLAMP(r.ierror,-r.imax,r.imax);
      r.duty = ((int16_t) (r.Kp*r.error + r.Ki*r.ierror)) * wduty;
    } else {
      if(s.ttipavg <= r.target){
        r.duty = wduty;
        r.error = 12.0;
        r.ierror = 0.0;
      } else {
        r.duty = MIN_DUTY;
        r.error = 0.0;
        r.ierror = 0.0;
      }
    }

    // detect if no tip is plugged in
    if (s.iin <= 0.001 && !(s.ttipavg >= r.target-r.deadband && s.ttipavg <= r.target+r.deadband)) {
      if (count > 4000) {
        r.duty = 0;
        r.error = 0.0;
        r.ierror = 0.0;
        r.derror = 0.0;
        wduty = 800;
        s.active = 0;
      } else {
        count++;
      }
    } else {
      count = 0;
      s.active = 1;
    }

    r.duty = CLAMP(r.duty, MIN_DUTY, MAX_DUTY); // Clamp to duty cycle

    if(s.iin > s.imax && r.duty > 800) { // Current limiting
      wduty = r.duty - 2;
      r.duty -= 800;
    } else if (s.iin > s.imax) {
      r.duty = 0;
    } else {
      wduty += 100;
      if(wduty >= MAX_DUTY) wduty = MAX_DUTY;
    }

    __HAL_TIM_SET_COMPARE(&htim1, TIM_CHANNEL_1, r.duty);
  } else {
    s.active = 0;
    __HAL_TIM_SET_COMPARE(&htim1, TIM_CHANNEL_1, 0);
  }

  __HAL_TIM_SET_COMPARE(&htim1, TIM_CHANNEL_4, 4000);
}

void HAL_TIM_PeriodElapsedCallback(TIM_HandleTypeDef *htim) //send USB cdc data
{
  if(sendDataUSB) // WIP need to fix this, should me timer based only
  {
    sendDataUSB = 0;

    USBD_CDC_SetTxBuffer(&USBD_Device, (uint8_t*)&UserTxBuffer[0], APP_TX_DATA_SIZE);
    USBD_CDC_TransmitPacket(&USBD_Device);
  }
}

void USB_printfloat(float _buf){
  memset(UserTxBuffer, 0, APP_TX_DATA_SIZE);
  sprintf((char * restrict) UserTxBuffer, "%d.%d \r\n", (uint16_t)_buf,(uint16_t)((_buf-(uint16_t)_buf)*10.0f));
  sendDataUSB = 1;
}


// init code sequence by Ralim, thanks alot!
#define DEVICEADDR_OLED   (0x3c<<1)
#define OLED_WIDTH        96
#define FRAMEBUFFER_START 17
uint8_t screenBuffer[16 + (OLED_WIDTH * 2) + 10];  // The data buffer
const uint8_t REFRESH_COMMANDS[17] = { 0x80, 0xAF, 0x80, 0x21, 0x80, 0x20, 0x80, 0x7F, 0x80, 0xC0, 0x80, 0x22, 0x80, 0x00, 0x80, 0x01, 0x40 };
uint8_t OLED_Setup_Array[] = {
0x80, 0xD5, /*Set display clock divide ratio / osc freq*/
0x80, 0x80, /*Divide ratios*/
0x80, 0xA8, /*Set Multiplex Ratio*/
0x80, 0x0F, /*16 == max brightness,39==dimmest*/
0x80, 0xC8, /*Set COM Scan direction*/
0x80, 0xD3, /*Set vertical Display offset*/
0x80, 0x00, /*0 Offset*/
0x80, 0x40, /*Set Display start line to 0*/
0x80, 0xA0, /*Set Segment remap to normal*/
0x80, 0x8D, /*Charge Pump*/
0x80, 0x14, /*Charge Pump settings*/
0x80, 0xDA, /*Set VCOM Pins hardware config*/
0x80, 0x02, /*Combination 2*/
0x80, 0x81, /*Contrast*/
0x80, 0x33, /*^51*/
0x80, 0xD9, /*Set pre-charge period*/
0x80, 0x22, /*Pre charge period*/
0x80, 0xDB, /*Adjust VCOMH regulator ouput*/
0x80, 0x40, /*VCOM level*/
0x80, 0xA4, /*Enable the display GDDR*/
0x80, 0XA6, /*Normal display*/
0x80, 0x20, /*Memory Mode*/
0x80, 0x00 /*Wrap memory*/
};

void disp_on(void) {
  uint8_t power_on[] = {
    0x80, 0xAF /*Display on*/
  };
  HAL_I2C_Master_Transmit(&hi2c1,DEVICEADDR_OLED, &power_on[0], 2, 1000);
}

void disp_off(void) {
  uint8_t power_off[] = {
    0x80, 0xAE /*Display off*/
  };
  HAL_I2C_Master_Transmit(&hi2c1,DEVICEADDR_OLED, &power_off[0], 2, 1000);
}

//not Ralim anymore - https://datasheet.lcsc.com/szlcsc/1810010328_UG-Univision-Semicon-UG-9616TSWCG02_C88335.pdf 4.4.4
void disp_init(void) {
  // off
  disp_off();
  // configuration sequence
  memcpy(&screenBuffer[0], &REFRESH_COMMANDS[0], sizeof(REFRESH_COMMANDS));
  refresh();
  HAL_I2C_Master_Transmit(&hi2c1,DEVICEADDR_OLED, &OLED_Setup_Array[0], sizeof(OLED_Setup_Array), 1000);
  // repeat above to be sure
  disp_off();
  HAL_I2C_Master_Transmit(&hi2c1,DEVICEADDR_OLED, &OLED_Setup_Array[0], sizeof(OLED_Setup_Array), 1000);
  // clear by sending empty framebuffer
  clear_screen();
  refresh();
  // on after 100 ms
  HAL_Delay(100);
  disp_on();
}

void refresh(void) {
  HAL_I2C_Master_Transmit(&hi2c1,DEVICEADDR_OLED, screenBuffer,FRAMEBUFFER_START + (OLED_WIDTH * 2),1000);
}

void clear_screen(void) {
  memset(&screenBuffer[FRAMEBUFFER_START], 0, OLED_WIDTH * 2);
}
void set_screen(void) {
  memset(&screenBuffer[FRAMEBUFFER_START], 255, OLED_WIDTH * 2);
}

void draw_v_line(int16_t x, int16_t y, uint16_t h, uint8_t color){
  for(int i = 0; i <= h; i++){
    write_pixel(x, y+i, color);
  }
}

void write_pixel(int16_t x, int16_t y, uint8_t color){
  if(x>95 || y >15){
    return;
  }
  if(color == 1){
    screenBuffer[FRAMEBUFFER_START + (x + ((y/8)*96))] |=  (1 << y % 8);
  } else if (color == 0){
    screenBuffer[FRAMEBUFFER_START + (x + ((y/8)*96))] &= ~(1 << y % 8);
  }
}

#define CHAR_WIDTH 6
#define CHAR_HEIGHT 8
void draw_char(unsigned char c, uint8_t x, uint8_t y, uint8_t brightness) {
    c = c & 0x7F;
    if (c < ' ') {
        c = 0;
    } else {
        c -= ' ';
    }
    uint8_t * chr = (uint8_t *) font[c];
    for (uint8_t j=0; j<CHAR_WIDTH; j++) {
        for (uint8_t i=0; i<CHAR_HEIGHT; i++) {
            if (chr[j] & (1<<i)) {
                write_pixel(x+j, y+i, 1);
            } else {
                write_pixel(x+j, y+i, 0);
            }
        }
    }
}

void draw_string(const unsigned char* str, uint8_t x, uint8_t y, uint8_t brightness) {
    while (*str) {
        draw_char(*str++, x, y, brightness);
        x += CHAR_WIDTH;
    }
}

void SystemClock_Config(void)
{
  RCC_OscInitTypeDef RCC_OscInitStruct = {0};
  RCC_ClkInitTypeDef RCC_ClkInitStruct = {0};
  RCC_PeriphCLKInitTypeDef PeriphClkInit = {0};

  RCC_OscInitStruct.OscillatorType = RCC_OSCILLATORTYPE_HSI|RCC_OSCILLATORTYPE_HSI14
                              |RCC_OSCILLATORTYPE_HSI48;
  RCC_OscInitStruct.HSIState = RCC_HSI_ON;
  RCC_OscInitStruct.HSI48State = RCC_HSI48_ON;
  RCC_OscInitStruct.HSI14State = RCC_HSI14_ON;
  RCC_OscInitStruct.HSICalibrationValue = RCC_HSICALIBRATION_DEFAULT;
  RCC_OscInitStruct.HSI14CalibrationValue = 16;
  RCC_OscInitStruct.PLL.PLLState = RCC_PLL_ON;
  RCC_OscInitStruct.PLL.PLLSource = RCC_PLLSOURCE_HSI48;
  RCC_OscInitStruct.PLL.PLLMUL = RCC_PLL_MUL2;
  RCC_OscInitStruct.PLL.PREDIV = RCC_PREDIV_DIV2;
  HAL_RCC_OscConfig(&RCC_OscInitStruct);

  RCC_ClkInitStruct.ClockType = RCC_CLOCKTYPE_HCLK|RCC_CLOCKTYPE_SYSCLK
                              |RCC_CLOCKTYPE_PCLK1;
  RCC_ClkInitStruct.SYSCLKSource = RCC_SYSCLKSOURCE_PLLCLK;
  RCC_ClkInitStruct.AHBCLKDivider = RCC_SYSCLK_DIV1;
  RCC_ClkInitStruct.APB1CLKDivider = RCC_HCLK_DIV1;

  HAL_RCC_ClockConfig(&RCC_ClkInitStruct, FLASH_LATENCY_1);

  PeriphClkInit.PeriphClockSelection = RCC_PERIPHCLK_USB|RCC_PERIPHCLK_I2C1;
  PeriphClkInit.I2c1ClockSelection = RCC_I2C1CLKSOURCE_HSI;
  PeriphClkInit.UsbClockSelection = RCC_USBCLKSOURCE_HSI48;

  HAL_RCCEx_PeriphCLKConfig(&PeriphClkInit);
}

static void MX_ADC_Init(void)
{
  __HAL_RCC_DMA1_CLK_ENABLE();
  __HAL_RCC_ADC1_CLK_ENABLE();

  ADC_ChannelConfTypeDef sConfig = {0};

  hadc.Instance = ADC1;
  hadc.Init.ClockPrescaler = ADC_CLOCK_ASYNC_DIV1;
  hadc.Init.Resolution = ADC_RESOLUTION_12B;
  hadc.Init.DataAlign = ADC_DATAALIGN_RIGHT;
  hadc.Init.ScanConvMode = ADC_SCAN_DIRECTION_FORWARD;
  hadc.Init.EOCSelection = ADC_EOC_SEQ_CONV;
  hadc.Init.LowPowerAutoWait = DISABLE;
  hadc.Init.LowPowerAutoPowerOff = DISABLE;
  hadc.Init.ContinuousConvMode = DISABLE;
  hadc.Init.DiscontinuousConvMode = DISABLE;
  hadc.Init.ExternalTrigConv = ADC_EXTERNALTRIGCONV_T1_CC4;//ADC_EXTERNALTRIGCONV_T2_TRGO;
  hadc.Init.ExternalTrigConvEdge = ADC_EXTERNALTRIGCONVEDGE_RISING;
  hadc.Init.DMAContinuousRequests = ENABLE;
  hadc.Init.Overrun = ADC_OVR_DATA_PRESERVED;
  HAL_ADC_Init(&hadc);

  sConfig.Channel = ADC_CHANNEL_0;
  sConfig.Rank = ADC_RANK_CHANNEL_NUMBER;
  sConfig.SamplingTime = ADC_SAMPLETIME_71CYCLES_5;
  HAL_ADC_ConfigChannel(&hadc, &sConfig);

  sConfig.Channel = ADC_CHANNEL_1;
  HAL_ADC_ConfigChannel(&hadc, &sConfig);

  sConfig.Channel = ADC_CHANNEL_2;
  HAL_ADC_ConfigChannel(&hadc, &sConfig);

  sConfig.Channel = ADC_CHANNEL_5;
  HAL_ADC_ConfigChannel(&hadc, &sConfig);

  HAL_ADC_MspInit(&hadc);
}

static void MX_I2C1_Init(void)
{

  hi2c1.Instance = I2C1;
  hi2c1.Init.Timing = 0x0000020B;
  hi2c1.Init.OwnAddress1 = 0;
  hi2c1.Init.AddressingMode = I2C_ADDRESSINGMODE_7BIT;
  hi2c1.Init.DualAddressMode = I2C_DUALADDRESS_DISABLE;
  hi2c1.Init.OwnAddress2 = 0;
  hi2c1.Init.OwnAddress2Masks = I2C_OA2_NOMASK;
  hi2c1.Init.GeneralCallMode = I2C_GENERALCALL_DISABLE;
  hi2c1.Init.NoStretchMode = I2C_NOSTRETCH_DISABLE;
  HAL_I2C_Init(&hi2c1);

  HAL_I2CEx_ConfigAnalogFilter(&hi2c1, I2C_ANALOGFILTER_ENABLE);

  HAL_I2CEx_ConfigDigitalFilter(&hi2c1, 0);
}

static void MX_IWDG_Init(void)
{
  hiwdg.Instance = IWDG;
  hiwdg.Init.Prescaler = IWDG_PRESCALER_4;
  hiwdg.Init.Window = 4095;
  hiwdg.Init.Reload = 4095;
  HAL_IWDG_Init(&hiwdg);
}

static void TIM3_Init(void)
{
  __HAL_RCC_TIM3_CLK_ENABLE();
  TIM_ClockConfigTypeDef sClockSourceConfig = {0};

  /*
       + Period = 10000 - 1
       + Prescaler = ((8000000/2)/10000) - 1

  */
  htim3.Instance = TIM3;
  htim3.Init.Period = (CDC_POLLING_INTERVAL*1000) - 1;
  htim3.Init.Prescaler = 399;
  htim3.Init.ClockDivision = 0;
  htim3.Init.CounterMode = TIM_COUNTERMODE_UP;
  htim3.Init.AutoReloadPreload = TIM_AUTORELOAD_PRELOAD_DISABLE;
  if(HAL_TIM_Base_Init(&htim3) != HAL_OK)
  {
    /* Initialization Error */
    Error_Handler();
  }
  sClockSourceConfig.ClockSource = TIM_CLOCKSOURCE_INTERNAL;
  HAL_TIM_ConfigClockSource(&htim3, &sClockSourceConfig);
}

static void MX_TIM1_Init(void)
{

  __HAL_RCC_TIM1_CLK_ENABLE();

  TIM_ClockConfigTypeDef sClockSourceConfig = {0};
  TIM_MasterConfigTypeDef sMasterConfig = {0};
  TIM_OC_InitTypeDef sConfigOC = {0};
  TIM_BreakDeadTimeConfigTypeDef sBreakDeadTimeConfig = {0};

  htim1.Instance = TIM1;
  htim1.Init.Prescaler = 6; // 2048
  htim1.Init.CounterMode = TIM_COUNTERMODE_UP;
  htim1.Init.Period = 4096; // 4096
  htim1.Init.ClockDivision = TIM_CLOCKDIVISION_DIV1;
  htim1.Init.RepetitionCounter = 0;
  htim1.Init.AutoReloadPreload = TIM_AUTORELOAD_PRELOAD_ENABLE;
  HAL_TIM_Base_Init(&htim1);

  sClockSourceConfig.ClockSource = TIM_CLOCKSOURCE_INTERNAL;
  HAL_TIM_ConfigClockSource(&htim1, &sClockSourceConfig);

  HAL_TIM_PWM_Init(&htim1);
  HAL_TIM_OC_Init(&htim1);

  sMasterConfig.MasterOutputTrigger = TIM_TRGO_RESET;
  sMasterConfig.MasterSlaveMode = TIM_MASTERSLAVEMODE_DISABLE;
  HAL_TIMEx_MasterConfigSynchronization(&htim1, &sMasterConfig);

  sConfigOC.OCMode = TIM_OCMODE_PWM1;
  sConfigOC.Pulse = 0;
  sConfigOC.OCPolarity = TIM_OCPOLARITY_HIGH;
  sConfigOC.OCNPolarity = TIM_OCNPOLARITY_HIGH;
  sConfigOC.OCFastMode = TIM_OCFAST_DISABLE;
  sConfigOC.OCIdleState = TIM_OCIDLESTATE_RESET;
  sConfigOC.OCNIdleState = TIM_OCNIDLESTATE_RESET;
  HAL_TIM_PWM_ConfigChannel(&htim1, &sConfigOC, TIM_CHANNEL_1);

  sConfigOC.OCMode = TIM_OCMODE_PWM2;
  sConfigOC.Pulse = 10;
  HAL_TIM_OC_ConfigChannel(&htim1, &sConfigOC, TIM_CHANNEL_4);

  sBreakDeadTimeConfig.OffStateRunMode = TIM_OSSR_DISABLE;
  sBreakDeadTimeConfig.OffStateIDLEMode = TIM_OSSI_DISABLE;
  sBreakDeadTimeConfig.LockLevel = TIM_LOCKLEVEL_OFF;
  sBreakDeadTimeConfig.DeadTime = 0;
  sBreakDeadTimeConfig.BreakState = TIM_BREAK_DISABLE;
  sBreakDeadTimeConfig.BreakPolarity = TIM_BREAKPOLARITY_HIGH;
  sBreakDeadTimeConfig.AutomaticOutput = TIM_AUTOMATICOUTPUT_DISABLE;
  HAL_TIMEx_ConfigBreakDeadTime(&htim1, &sBreakDeadTimeConfig);

  HAL_TIM_MspPostInit(&htim1);
}
/*
static void MX_TIM2_Init(void)
{
  TIM_ClockConfigTypeDef sClockSourceConfig = {0};
  TIM_MasterConfigTypeDef sMasterConfig = {0};
  TIM_OC_InitTypeDef sConfigOC = {0};

  htim2.Instance = TIM2;
  htim2.Init.Prescaler = 2096;
  htim2.Init.CounterMode = TIM_COUNTERMODE_UP;
  htim2.Init.Period = 4096;
  htim2.Init.ClockDivision = TIM_CLOCKDIVISION_DIV4;
  htim2.Init.AutoReloadPreload = TIM_AUTORELOAD_PRELOAD_ENABLE;
  HAL_TIM_PWM_Init(&htim2);

  sClockSourceConfig.ClockSource = TIM_CLOCKSOURCE_INTERNAL;
  HAL_TIM_ConfigClockSource(&htim2, &sClockSourceConfig);

  sMasterConfig.MasterOutputTrigger = TIM_TRGO_UPDATE;
  sMasterConfig.MasterSlaveMode = TIM_MASTERSLAVEMODE_DISABLE;
  HAL_TIMEx_MasterConfigSynchronization(&htim2, &sMasterConfig);

  sConfigOC.OCMode = TIM_OCMODE_PWM1;
  sConfigOC.Pulse = 30;
  sConfigOC.OCPolarity = TIM_OCPOLARITY_HIGH;
  sConfigOC.OCFastMode = TIM_OCFAST_DISABLE;
  HAL_TIM_PWM_ConfigChannel(&htim2, &sConfigOC, TIM_CHANNEL_2);

  HAL_TIM_MspPostInit(&htim2);

}
*/

static void MX_DMA_Init(void)
{
  __HAL_RCC_DMA1_CLK_ENABLE();

  HAL_NVIC_SetPriority(DMA1_Channel1_IRQn, 0, 0);
  HAL_NVIC_EnableIRQ(DMA1_Channel1_IRQn);

  HAL_NVIC_SetPriority(TIM3_IRQn, 0, 0);
  HAL_NVIC_EnableIRQ(TIM3_IRQn);
  /*
  HAL_NVIC_SetPriority(DMA1_Channel2_3_IRQn, 0, 0);
  HAL_NVIC_EnableIRQ(DMA1_Channel2_3_IRQn);
  HAL_NVIC_SetPriority(DMA1_Channel4_5_6_7_IRQn, 0, 0);
  HAL_NVIC_EnableIRQ(DMA1_Channel4_5_6_7_IRQn);
  */

}
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

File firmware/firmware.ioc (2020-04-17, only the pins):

Mcu.UserName=STM32F072CBUx
PA0.GPIO_Label=IIN
PA0.Signal=ADC_IN0
PA1.GPIO_Label=TTIP
PA1.Signal=ADC_IN1
PA11.Signal=USB_DM
PA12.Signal=USB_DP
PA13.Signal=SYS_SWDIO
PA14.Signal=SYS_SWCLK
PA2.GPIO_Label=UIN
PA2.Signal=ADC_IN2
PA3.GPIO_Label=B1
PA3.Signal=GPIO_Input
PA4.GPIO_Label=B2
PA4.Signal=GPIO_Input
PA5.GPIO_Label=TREF
PA5.Signal=ADC_IN5
PB10.GPIO_Label=STUSB_SCL
PB10.Signal=I2C2_SCL
PB11.GPIO_Label=STUSB_SDA
PB11.Signal=I2C2_SDA
PB12.GPIO_Label=INT_N
PB12.Signal=GPIO_Input
PB3.GPIO_Label=PWMOUT
PB3.Signal=S_TIM2_CH2
PB6.GPIO_Label=OLED_SCL
PB6.Signal=I2C1_SCL
PB7.GPIO_Label=OLED_SDA
PB7.Signal=I2C1_SDA

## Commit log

2020-04-15 added gitignore
    [BOM.csv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]
2020-04-15 added 3D files
    [Stackup.FCStd]
2020-04-15 added v1.0
    [C245_conn-B_Cu.gbl, C245_conn-B_Mask.gbs, C245_conn-B_Paste.gbp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]
2020-04-17 added pdf
    [C245_conn.sch]
2020-04-30 updated files
    [USB_conn-B_Cu.gbl, USB_conn-B_Mask.gbs, USB_conn-B_Paste.gbp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]
2020-05-07 increased PWM frequency, fixed crash bug when USB-C is plugged in first
    [main.c]
2020-06-30 lower current limit, remove d term
2020-06-30 i2c2 not doing anything
2020-06-30 setup PD profiles for 30 W and 80 W
    even though most USB PD adaptors will allow a device to draw the max
    advertised current, kosher ones will cut power if the profile has not
    been enumerated (Apple MacBook for example). Added initialisation of
    profiles at start up.
2020-07-01 following datasheet for display init in attempt to prevent noise at boot sometimes
    [main.c]
2020-07-01 OLED start routine ds parity, PID tune
2020-07-01 integrator more applied for trim and current clamp hard
2020-07-02 stusb4500 driver in separate files
2020-07-02 think I've got screen working always 🤞
2021-02-07 Add missing 3D models
    [Diodes_-_DMP3017SFG-7.step, OtterIron_PRO_Bot.kicad_pcb, cap_el_horizontal_d10_h20_p5_w0.6.stp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]

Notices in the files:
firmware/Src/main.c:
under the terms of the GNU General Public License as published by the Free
